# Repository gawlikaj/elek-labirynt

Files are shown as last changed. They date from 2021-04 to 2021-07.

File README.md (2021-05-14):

# elek-labirynt
Handheld Video Game

## Goals
1. Learn how to use EagleCAD (or KiCAD) to develop a PCB design for the project that will connect all hardware that the software is dependent on.
1. Write a bill of materials
1. Apply knowledge and understanding from online coursework and prior in-person coursework into an independent project. (interrupts, finite state machines, usage of GIT, interaction with an LCD display, interaction with analog devices and fundamentals of an RTOS)
1. Learn how the ESP32 microcontroller functions (and how it relates to the chosen board that I will be working with)
1. Develop drivers for SPI-controlled LCD/SD Card, I2C-controlled joystick and LiPo fuel gauge, and GPIO devices connected to the board I am using
1. Consider using and learning how a specific RTOS works such as FreeRTOS
1. Develop a hand-held game via either baremetal firmware programming or code that will run on chosen RTOS (based on #4) utilizing what I did on a text-based high school project

## Notes
The hardware documentation and any media is licensed under the Creative Commons License.  The software and its documentation are licensed under the GNU Public License.

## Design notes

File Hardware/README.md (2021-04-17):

# elek-labirynt Hardware

Hardware Designs and bill of materials for the elek-labirynt project.  I, Andrew Gawlik, have utilized SparkFun parts, their EagleCAD library, 
and their EagleCAD files to create library parts for the schematic and PCB designs as licensed under the Creative Commons Attribution Share-Alike 4.0 License.

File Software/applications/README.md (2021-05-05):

# Applications

This directory contains the test applications and the game engine.  The test applications are designed to test the effectiveness of the drivers implemented.

# Application Layout

The applications are grouped into subdirectories:  Driver_Test and Full_Apps:

* `Driver_Test/UART_Debugger_Test` contains the test application used for the UART debugger driver

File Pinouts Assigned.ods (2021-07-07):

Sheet: Pins
ESP32 Pin # | ESP32 Label | GPIO # | Signal on Thing Plus | Pin on Thing Plus | Signal Type | Signal on Design | Protocol | Function | Device/Driver
25 | IO0 | 0 | 0 | NC | I/O | Unused | NA | Unused | N/A
35 | TXD0 | 1 | RX | NC | I/O | Not Connected on board, but via USB cable | UART |  | Debugger
24 | IO2 | 2 | NA | NC | I/O | Unused | NA | Unused | N/A
34 | RXD0 | 3 | TX | NC | I/O | Not Connected on board, but via USB cable | UART |  | Debugger
26 | IO4 | 4 | A5 | 10@J4 | I/O | BUTTON1 | NA | Button 1 Input | Button 1
29 | IO5 | 5 | SCK | 11@J4 | I/O | SCLK | SPI | Serial Clock | LCD15143
20 | CLK | 6 | NA | NC | I/O | Unused | SPI | Serial Clock | Integrated Flash
21 | SD0 | 7 | NA | NC | I/O | Unused | SPI | Data 0 | Integrated Flash
22 | SD1 | 8 | NA | NC | I/O | Unused | SPI | Data 1 | Integrated Flash
17 | SD2 | 9 | NA | NC | I/O | Unused | SPI | Data 2 | Integrated Flash
18 | SD3 | 10 | NA | NC | I/O | Unused | SPI | Data 3 | Integrated Flash
19 | CMD | 11 | NA | NC | I/O | Unused | SPI | Command | Integrated Flash
14 | IO12 | 12 | 12 | 5@J2 | I/O | BUTTON2 | NA | Button 2 Input | Button 2
16 | IO13 | 13 | 13 | 4@J2 | I/O | BUTTON3 | NA | Button 3 Input | Button 3
13 | IO14 | 14 | 14 | 10@J2 | I/O | LCDCS | SPI | Chip Select for LCD | LCD15143
23 | IO15 | 15 | 15 | 8@J2 | I/O | DC | NA | Data/Command | LCD15143
27 | IO16 | 16 | 16 | 14@J4 | I/O | AWAKE | NA | Awake Switch | Switch
28 | IO17 | 17 | 17 | 15@J4 | I/O | TE | NA | Tearing Effect | LCD15143
30 | IO18 | 18 | COPI | 12@J4 | I/O | CIPO | SPI | Controller Input Peripheral Output | LCD15143
31 | IO19 | 19 | CIPO | 13@J4 | I/O | COPI | SPI | Controller Output Peripheral Input | LCD15143
33 | IO21 | 21 | 21 | 16@J4 | I/O | PWM | NA | Backlight Dimming | LCD15143
36 | IO22 | 22 | SCL | 11@J2 | I/O | Not Connected on board, but via Qwiic Cable | I2C | SCL | Joystick, Fuel Gauge
37 | IO23 | 23 | SDA | 12@J2 | I/O | Not Connected on board, but via Qwiic Cable | I2C | SDA | Joystick, Fuel Gauge
10 | IO25 | 25 | A1 | 6@J4 | I/O | LSPK | DAC | Left Speaker Analog Signal | Left Speaker
11 | IO26 | 26 | A0 | 5@J4 | I/O | RSPK | DAC | Right Speaker Analog Signal | Right Speaker
12 | IO27 | 27 | 27 | 6@J2 | I/O | SDCS | SPI | Chip Select for SD Card | LCD15143
8 | IO32 | 32 | 32 | 9@J2 | I/O | BUTTON0 | NA | Button 0 Input | Button 0
9 | IO33 | 33 | 33 | 7@J2 | I/O | Unused | NA | Unused | N/A
6 | IO34 | 34 | A2 | 7@J4 | Input | Unused | NA | Unused | N/A
7 | IO35 | 35 | NA | NC | Input | Unused | NA | Unused | N/A
4 | SENSOR_VP | 36 | A4 | 9@J4 | Input | BUTTON4 | NA | Button 4 Input | Button 4
5 | SENSOR_VN | 39 | A3 | 8@J4 | Input | Unused | NA | Unused | N/A
3 | EN | NA | CHIP_PU | 1@J4 | Input | Unused | NA | Reset Button | Thing Plus
2 | 3V3 | NA | 3V3 | 2@J4 | Power | 3V3 | NA | Power Supply | All
1 | GND | NA | GND | 4@J4 | Power | DGND | NA | Ground | All
15 | GND | NA | GND | 4@J4 | Power | DGND | NA | Ground | All
38 | GND | NA | GND | 4@J4 | Power | DGND | NA | Ground | All
32 | NC | NA | NA | NC | NA | Unused | NA | Unused | N/A

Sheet: Interrupts
Interrupt | Device | Type
22 | Momentary Pushbuttons | GPIO
none | LCD15143/SPI | I/O
 | Qwiic/Joystick/FuelGauge | Timer
 | DAC1/DAC2 | Timer
 | SleepSwitch | RTCIO

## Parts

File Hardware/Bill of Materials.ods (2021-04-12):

Level | Part Number | Description | QTY | Unit | Unit Cost | Extended Cost | Source | Seller Part Number
0 |  | Complete Hardware Assembly | 1 | Ea |  |  | Self | N/A
1 |  | Momentary Pushbutton Switch - 12mm Square | 1 | Ea | $0.50 | $0.50 | Sparkfun | COM-09190
1 |  | Multicolor Buttons – 4-pack | 1 | Ea | $1.60 | $1.60 | Sparkfun | PRT-14460
1 |  | SparkFun Thing Plus - ESP32 WROOM (U.FL) | 1 | Ea | $20.95 | $20.95 | Sparkfun | WRL-17381
1 |  | SparkFun TFT LCD Breakout - 1.8" (128x160) | 1 | Ea | $29.95 | $29.95 | Sparkfun | LCD-15143
1 |  | SparkFun Qwiic Joystick | 1 | Ea | $10.50 | $10.50 | Sparkfun | COM-15168
1 |  | Mini Speaker - PC Mount 12mm 2.048kHz | 2 | Ea | $1.95 | $3.90 | Sparkfun | COM-07950
1 |  | RES 10K OHM 1/4W 5% AXIAL | 10 | Ea | $0.10 | $1.00 | DigiKey | 10KQBK-ND
1 |  | Lithium Ion Battery – 2Ah | 1 | Ea | $12.95 | $12.95 | Sparkfun | PRT-13855
1 |  | Female Headers | 4 | Ea | $1.50 | $6.00 | Sparkfun | PRT-00115
1 |  | Break Away Headers – Straight | 4 | Ea | $1.50 | $6.00 | Sparkfun | PRT-00116
1 |  | Custom PCB – tentative | 1 | Ea |  |  | Researching | N/A
2 |  | PCB Design and Gerber Files | 1 | Ea |  |  | Self | N/A
3 |  | EagleCAD Free Version | 1 | Ea | $0.00 | $0.00 | Eagle
1 |  | SOLDER LF SN96 21GAUGE .25LBS | 1 | Ea | $33.74 | $33.74 | DigiKey | 473-1102-ND
1 |  | DESOLDER BRAID ROSIN 0.1" 5' | 1 | Ea | $4.33 | $4.33 | DigiKey | 473-1169-ND
1 |  | Lexar Professional LSDMI32GBNL633A 633x Micro SDHC 32GB UHS-I Card with SD Adapter | 1 | Ea | $12.99 | $12.99 | Staples | 24359322
1 |  | LED - Assorted (20 pack) | 1 | Ea | $3.30 | $3.30 | Sparkfun | COM-12062
1 |  | Mini Power Switch – SPDT | 1 | Ea | $1.50 | $1.50 | Sparkfun | COM-00102

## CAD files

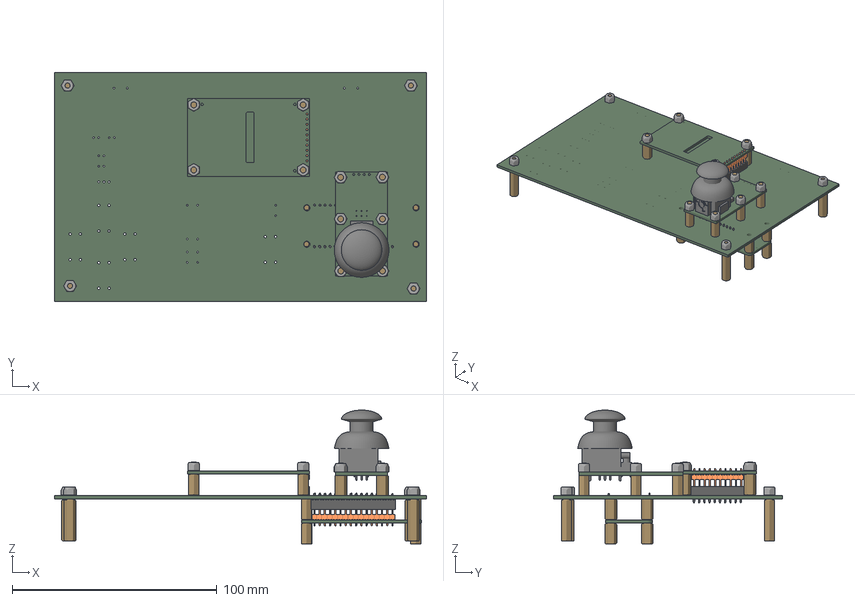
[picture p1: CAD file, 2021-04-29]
Hardware/FreeCad/Assembly with Complete Board.FCStd
181.6 x 111.8 x 65.4 mm
Pin Header - Female - 2.54mm 16pin
Pin Header - Female - 2.54mm 12pin
Pin Header - Female - 2.54mm 10pin
Unified Board
M3_M_TO_F_20MM_STANDOFF C0
M3_M_TO_F_20MM_STANDOFF C1
M3_M_TO_F_20MM_STANDOFF C2
M3_M_TO_F_20MM_STANDOFF C3
hex lock nut m3 C0
hex lock nut m3 C1
hex lock nut m3 C2
hex lock nut m3 C3
Breakout Board COM-15168
M3_M_TO_F_10MM_STANDOFF J0
M3_M_TO_F_10MM_STANDOFF J1
M3_M_TO_F_10MM_STANDOFF J2
M3_M_TO_F_10MM_STANDOFF J3
M3_M_TO_F_10MM_STANDOFF J4
M3_M_TO_F_10MM_STANDOFF J5
hex lock nut m3 J0
hex lock nut m3 J1
hex lock nut m3 J2
hex lock nut m3 J3
hex lock nut m3 J4
hex lock nut m3 J5
Breakout Board WRL-17381
ZL201-40_P2-54_L101_W2-54_H8-011 16pin
ZL201-40_P2-54_L101_W2-54_H8-010 12pin
M3_M_TO_F_10MM_STANDOFF E0
M3_M_TO_F_10MM_STANDOFF E1
M3_M_TO_F_10MM_STANDOFF E2
M3_M_TO_F_10MM_STANDOFF E3
M3_F_TO_F_10MM_STANDOFF E0
M3_F_TO_F_10MM_STANDOFF E1
M3_F_TO_F_10MM_STANDOFF E2
M3_F_TO_F_10MM_STANDOFF E3
Breakout Board LCD-15143
ZL201-40_P2-54_L101_W2-54_H8-9 10pin
M3_M_TO_F_10MM_STANDOFF L0
M3_M_TO_F_10MM_STANDOFF L1
M3_M_TO_F_10MM_STANDOFF L2
M3_M_TO_F_10MM_STANDOFF L3
hex lock nut m3 L0
hex lock nut m3 L1
hex lock nut m3 L2
hex lock nut m3 L3

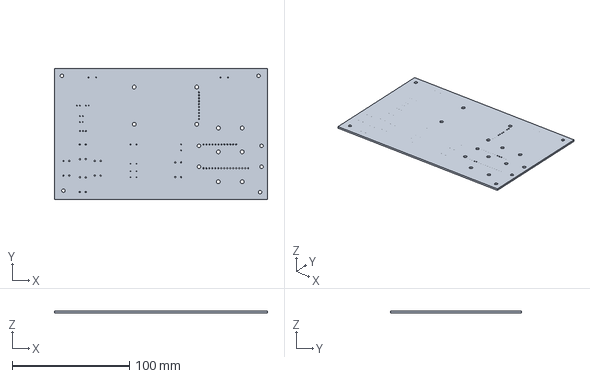
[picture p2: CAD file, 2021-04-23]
Hardware/StepExport/CompleteBoard.step
181.6 x 111.8 x 1.60 mm

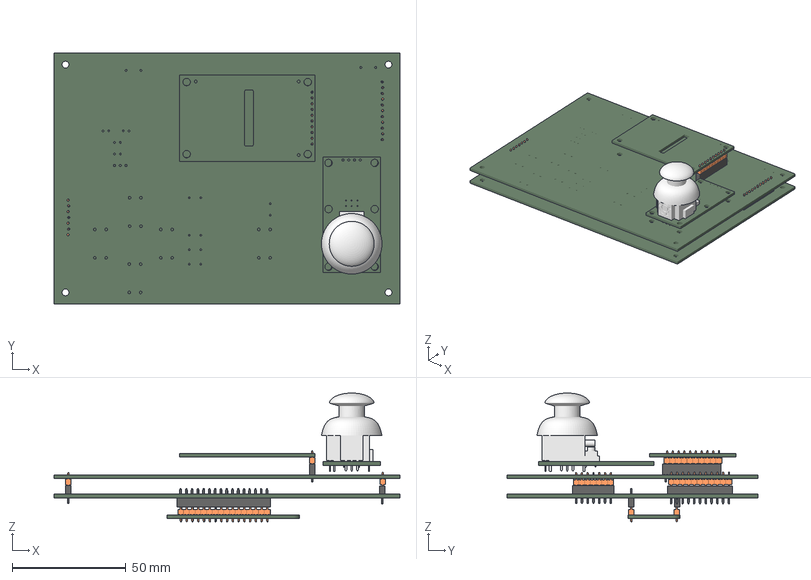
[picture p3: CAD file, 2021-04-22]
Hardware/FreeCad/Assembly with Separate Boards.FCStd
152.4 x 110.5 x 56.8 mm
Pin Header - Female - 2.54mm 10pin
ZL201-40_P2-54_L101_W2-54_H8-9 7pin
ZL201-40_P2-54_L101_W2-54_H8-9 11pin
ZL201-40_P2-54_L101_W2-54_H8-9 10pin
ZL201-40_P2-54_L101_W2-54_H8-011 16pin
ZL201-40_P2-54_L101_W2-54_H8-010 12pin
Pin Header - Female - 2.54mm 12pin
Pin Header - Female - 2.54mm 16pin
Pin Header - Female - 2.54mm 7pin
Pin Header - Female - 2.54mm 11pin

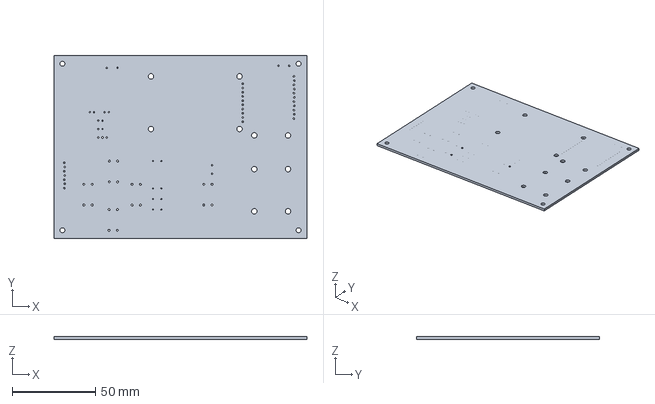
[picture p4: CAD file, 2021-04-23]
Hardware/StepExport/InterfaceBoard.step
152.4 x 110.5 x 1.60 mm

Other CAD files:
Hardware/StepExport/ControllerBoard.step

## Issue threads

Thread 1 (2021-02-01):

Write Bill of Materials

gawlikaj, 2021-02-01:
Write the bill of materials for components used

gawlikaj, 2021-02-01:
Initial Bill of Materials has been create, but part numbers will need to be assigned and more investigation will need to be done regarding pricing of a custom PCB, currently considering vendors that will be reasonably priced for a prototype board.  Considering contingencies if a prototype board is outside of price range.

gawlikaj, 2021-02-09:
Draft of bill of materials has been completed, the rest of the bill of materials is contingent on completion of PCB design and cost of a custom PCB.  Starting new issue after PCB design draft is completed to investigate costs.

Closed 2021-02-09.

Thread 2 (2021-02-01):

Design PCB Layout from Bill of Materials (Interface Board)

gawlikaj, 2021-02-01:
Design the PCB Layout from the Bill of Materials

gawlikaj, 2021-02-01:
Currently 10 buttons and pulldown resistors have been added to the interface board.  Need to convert schematics of SparkFun boards to footprints for my use in the PCB layout

gawlikaj, 2021-02-09:
Still need to convert SparkFun boards to library parts (the schematic part to symbol was simple, but it will take time to precisely define the footprint from the provided board layout).  I have posted a question on the AutoDesk Eagle forum looking for a suggestion to make this conversion less prone to mistakes :  https://forums.autodesk.com/t5/eagle-forum/looking-to-convert-a-pre-manufactured-board-to-library/td-p/10051636

It has gone unanswered for a week and I may consider implementation in KiCad in an effort to continue this.  I already have a KiCad converted top board. Since KiCad does not limit how many layers I can use and it converts Eagle boards/schematics fairly well, I will begin investigating to see how to create a library part in KiCad.

gawlikaj, 2021-02-10:
The SparkFun Eagle files have been imported into KiCad with some warnings related to certain layers being unsupported.  Considering the intent to make them parts that will go on the board being designed, that would be of little consequence.

gawlikaj, 2021-02-11:
Found an interesting approach to creating the library item from the part documented on a forum elsewhere:  https://forum.arduino.cc/index.php?topic=175306.0

gawlikaj, 2021-04-02:
I generated the library versions of the four breakout boards, though I do want to make some tweaks so that I may be able to use them properly in my board design.

gawlikaj, 2021-04-07:
I made the tweaks successfully and started wiring the next part of the board.  My current considerations include splitting this between the controller board and the interface board.

The interface board shall include the buttons, joysticks, speakers, LCD, switch and LEDs
The controller board shall include the microcontroller and the ADC along with the QWIIC cable.  In order to simplify this, I am renaming this issue to reference the interface board and will create a new issue referencing the controller board.

Since this is at the point where I plan to use multiple boards part of this work will also include planning where I will place headers.

gawlikaj, 2021-04-12:
The bill of materials has been updated on issue #8 therefore I will need to make some adjustments accordingly.  Since the Qwiic joystick can be handled through the Qwiic connector, I can leave it off the board design for the interface board, however, I will keep it in mind when I want to stabilize the devices with standoffs and such on the controller board.

gawlikaj, 2021-04-15:
Given the limitation on EagleCAD free edition that limits to 80cm^2, meaning it can be 8cmx10cm, it seems like it will be extremely difficult to produce a board with what I am trying to assemble.  I will instead add all of the components and develop the schematic via EagleCAD then place them and route the traces using KiCad in order to ensure that I can keep the parts and have more freedom to have a larger board, and quite possibly avoid having to design multiple boards.

gawlikaj, 2021-04-15:
For futher clarification on the aspect of multiple boards, KiCad allows for multiple layers, whereas I would need to pay for access to multiple layers on EagleCAD (just like with regards to the board size limitation).

gawlikaj, 2021-04-17:
Updated schematic parts here, as indicated earlier, I will likely find difficulty placing the parts and routing the traces on the board precisely due to board size limitations within the free version of EagleCAD, the schematic and board will be imported into KiCad to complete the process.

gawlikaj, 2021-04-20:
The parts have been fixed, but the board will need to be wired using KiCad in order to ensure enough board space.

gawlikaj, 2021-04-20:
KiCad import has been completed and wiring traces have been completed.  KiCad design rules checker found no problems.

Items to consider:  drill holes for standoffs, board shape, silk screening.

gawlikaj, 2021-04-20:
Also need to update the frame since the autoupdate from EagleCAD is not on KiCad

gawlikaj, 2021-04-20:
Drill holes for standoffs seem like they may need to be handled by adding another "special" part

gawlikaj, 2021-04-21:
Once the drill holes are in place I should be done with this particular board design.  The circuitry and traces have successfully been drawn out using only two PCB layers, which can be helpful in the event that a protoboard is chosen due to costs for ordering a custom PCB.

gawlikaj, 2021-04-21:
Drill holes added for standoffs, for now this is considered complete.

Closed 2021-04-21.

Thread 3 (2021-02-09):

Identification of Available RTOS for ESP32 microcontroller

gawlikaj, 2021-02-09:
Identify available RTOS that can be installed on the ESP32 microcontroller within reason

gawlikaj, 2021-02-09:
https://www.lynx.com/embedded-systems-learning-center/cost-of-a-real-time-operating-system-rtos

gawlikaj, 2021-02-09:
https://www.lynx.com/embedded-systems-learning-center/how-to-choose-a-real-time-operating-system-rtos

gawlikaj, 2021-04-13:
The only RTOS I see API documentation for related to the microcontroller I am using is FreeRTOS.  The C/C++ build system for the official ESP-IDF also uses FreeRTOS in its example files, I will look through to see if there are references to additional RTOS within the IDF.

gawlikaj, 2021-04-14:
After reviewing, the ESP-IDF is built around FreeRTOS, the only other way to get it to work with another RTOS or baremetal for that matter would be to build another framework.  I can look into this another time (it will still be a part of this project), but for now, it seems like FreeRTOS is the best choice for now seeing as it would require more investigation than practical for getting this to work for a project seemingly as simple as this.

Closed 2021-04-14.

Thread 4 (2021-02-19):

Document Hardware

gawlikaj, 2021-02-19:

gawlikaj, 2021-02-19:
Hardware documentation has begun, will also include links/pages regarding how this was implemented.

gawlikaj, 2021-02-19:
Hardware BOM and wiki page for hardware both match with the materials used as of 2021-02-19

gawlikaj, 2021-02-25:
Added documentation regarding a testing plan along with links to some of the datasheets on the wiki

gawlikaj, 2021-04-22:
As indicated on issue #16, the FreeCad assembly drawing will be included on the wiki documentation once it is completed.  Both versions will be included.

gawlikaj, 2021-05-17:
To make this easier, the hardware documentation will be split based on components.  Consequentially this will no longer be an ongoing task, but a tabled one for when the project is ready for assembly.

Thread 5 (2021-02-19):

Order and Receive Parts

gawlikaj, 2021-02-19:
Order and receive parts to begin working on the hardware (this excludes the PCB design as this is to test out a prototype before the PCB is designed)

gawlikaj, 2021-02-19:
SD card has been ordered from Staples, already have the solder, wick, and resistors.  Clarifying ordering information from SparkFun.

gawlikaj, 2021-02-22:
SD card has been received.

gawlikaj, 2021-03-22:
SparkFun order has been sent out, awaiting estimated delivery date

gawlikaj, 2021-03-29:
There is still a backorder on the ADC and the Qwiic cables (used to connect between the ESP32 Thing Plus Wroom and the ADC).

gawlikaj, 2021-04-01:
The Qwiic cables are now in stock, just waiting on the ADC... though I noticed that the breadboards are now out of stock and I am unsure how this will impact my order.  Sending a message to ask about that.

gawlikaj, 2021-04-02:
The breadboards are now showing up as available on the order, still waiting on the ADC.

gawlikaj, 2021-04-12:
The parts have been received today.... after careful inspection, while the ADC was on backorder, I noticed two things:
1) The Qwiic connector and the I2C pins are tied together so I cannot use them as additional GPIO
2) A single Qwiic joystick (I2C interface for the joystick vertical and horizontal interfaces along with the select button) was available

I decided to remove the ADC, both Joysticks and their breakout boards and replace with a single Qwiic joystick.  This will be documented on a revised version of the BOM and wiki.

Closed 2021-04-12.

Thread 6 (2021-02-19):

Add LEDs and Power Switch to Bill of Materials

gawlikaj, 2021-02-19:
LEDs and Power Switch have not been included in the bill of materials.

gawlikaj, 2021-02-19:
Added the LEDs and power switch to the bill of materials

gawlikaj, 2021-02-19:
this should be closed with the last issue update

Closed 2021-02-19.

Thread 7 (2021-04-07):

Design PCB Layout from Bill of Materials (Controller Board)

gawlikaj, 2021-04-07:
Once the interface board is completed, will need to establish a layout that connects the ADC and microcontroller to the headers to properly power up and interact with the interface board.

gawlikaj, 2021-04-17:
This will no longer use the ADC and only includes the microcontroller and headers.

gawlikaj, 2021-04-17:
The reasoning for not using the ADC is that the ADC part, thumb joystick and thumb breakout board parts were all replaced by a single part that has a joystick and performs the ADC and communicates via I2C using the Qwiic cable.

gawlikaj, 2021-04-21:
Use the header pin locations and standoff hole locations from the interface board so that they match up

gawlikaj, 2021-04-21:
The controller board design is complete in regards to existing BOM.

Closed 2021-04-21.

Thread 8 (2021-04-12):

Changes to the Bill of Materials -- Reduction of buttons

gawlikaj, 2021-04-12:
After inspection, the GPIO pins on the ESP32-WROOM Thing Plus suggested for I2C are hardwired to the Qwiic connector on the board.  This means that I need to reduce the number of I/O devices connected directly to the board.  The result, since I really did not need both sets of joysticks nor 10 buttons, was to cut the joysticks and buttons in half.

So now there will be 5 buttons and 1 joystick (this will be a Qwiic joystick as a single part instead of 3 separate parts).
Need to update the bill of materials and the Wiki.

gawlikaj, 2021-04-12:
Both the BOM and the Wiki have been updated reflecting the changes required.

Closed 2021-04-12.

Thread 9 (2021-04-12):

Test SparkFun Thing Plus - ESP32 WROOM (U.FL) -- UART

gawlikaj, 2021-04-12:
Start with some basic firmware for a hello world application that sends a message via UART.  UART seems to be the easiest way to perform debugging and having this piece will help greatly with being able to dump debugging data on regular intervals.  Wireless functionality will be considered on a future milestone after the standalone system is built and tested.

gawlikaj, 2021-04-13:
A useful starting point:
https://docs.espressif.com/projects/esp-idf/en/latest/esp32/get-started/establish-serial-connection.html

gawlikaj, 2021-04-14:
Currently investigating errors in eclipse with the IDF plugin on the project created from the template.

gawlikaj, 2021-04-14:
Using the UART echo project as a template for this part as a starting point

gawlikaj, 2021-04-14:
seems like it works better when I just use the command line interface

gawlikaj, 2021-04-14:
the hello world project executes correctly and I can monitor the data without a problem... now to create the driver and the test program

gawlikaj, 2021-04-14:
I will not include the hello world project in this repository since it was not my code, but I will include my project files (drivers and tests)

gawlikaj, 2021-04-14:
I will be using different parts of the UART example projects to implement this driver and the test program.  I reviewed some of the existing UART example projects.

Will start off with the basics of writing text on a timer to the UART then experiment with abstracting to fulfill the purposes.

gawlikaj, 2021-04-14:
The microcontroller UART has been tested successfully.

Closed 2021-04-14.

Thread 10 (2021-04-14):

UART Debugger Driver Development

gawlikaj, 2021-04-14:
Implement the driver to operate on timed interrupts and read a debugging message sent to it in order to reduce clutter when debugging the system.

gawlikaj, 2021-04-15:
Will be looking at the message buffer to send the data using FreeRTOS

gawlikaj, 2021-04-15:
The debugger will need to be a background task.

gawlikaj, 2021-04-15:
The message buffer is not available with the stable version of the ESP-IDF, currently reviewing the API documentation for the stable version to find a suitable alternative.

gawlikaj, 2021-04-15:
In order to prevent conflicts with the other IO pins on the board, I will need to specify pins for UART0 which is connected to the USB.

gawlikaj, 2021-04-15:
For further information on the UART configuration:
https://docs.espressif.com/projects/esp-idf/en/latest/esp32/api-reference/peripherals/uart.html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

gawlikaj, 2021-04-15:
I may be able to use the UART ring buffer with an ISR to handle debug output.  I can look into it while looking into the pins here:
https://www.espressif.com/sites/default/files/documentation/esp32_technical_reference_manual_en.pdf#uart

gawlikaj, 2021-04-27:
Including this with the breadboard testing project as it will be used for the breadboard testing portion as well...

gawlikaj, 2021-04-27:
As I realized, breadboard testing can be done independent of drivers.  The breadboard testing will use the drivers developed, but will be focused on verifying the functionality of devices by being plugged into the breadboard.  Since UART0 (the UART being used for this driver) can be interacted with via the USB cable, it is unnecessary to include it in breadboard testing, however, the pin assignments uses will be crucial to the design requirements for the rest of the system in order to ensure that there are no conflicts when using the UART Debugger Driver (which will mainly be used for testing).

gawlikaj, 2021-04-30:
Reviewing the API documentation and source code files from the EspressIF ESP32 IDF Programming Guide

gawlikaj, 2021-04-30:
https://i0.wp.com/randomnerdtutorials.com/wp-content/uploads/2018/08/esp32-pinout-chip-ESP-WROOM-32.png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

Has been helpful in identifying the default pins

gawlikaj, 2021-04-30:
Also to help with my project I have included a listing of pinouts for the SparkFun Thing Plus, the pinouts as demonstrated on the schematic for the SparkFun Thing Plus, and what they are wired to

gawlikaj, 2021-05-01:
It works having them set to their default pins (unfortunately the IDF does not seem to indicate which GPIOs these belong to), however after looking at the image for identifying the default pins, I am unsure.... I will need to verify using WaveForms with the logic analyzer to see if there are any signals being sent out to the other GPIO pins before I proceed further.  This would involve soldering the header pins to the SparkFun Thing Plus board.

gawlikaj, 2021-05-03:
After some review of the datasheets and creating a pinout map from microcontroller to thing plus to design, it appears that the default pins for TX and RX will not interfere with any devices... however, after reviewing the datasheet, the default CTS for UART0 appears to be IO19 which connects to the COPI signal and the default RTS for UART0 appears to be IO22 which connects to the SCL used in I2C communication.  However, in order to mitigate confusion I will specify the specific GPIO numbers to match the defaults for TX and RX and unused signals for RTS and CTS.

The current plan is:
RX   - GPIO3
TX   - GPIO1
CTS - GPIO2
RTS - GPIO35

gawlikaj, 2021-05-03:
I had to switch CTS and RTS GPIO numbers due to a kernel panic...

gawlikaj, 2021-05-04:
I am taking the opportunity to utilize the existing build system that the ESP-IDF is using for this project and it's involving some research into both CMake and the ESP-IDF.  The purpose of this is to allow the code to be modularized and so that extra copies of the files will not have to be used, especially with regards to making updates in one location and then potentially forgetting when they need to be used elsewhere...

gawlikaj, 2021-05-05:
The updated structure works as intended, I also switched to ESP-IDF v4.3 for the build system updates, which also includes features that were not available in v4.2... I can take the opportunity to utilize a more appropriate method of setting up the UART Debugger through some of the newer features available in FreeRTOS v10.

gawlikaj, 2021-05-05:
So now I will be investigating the usage of the message buffer

gawlikaj, 2021-05-06:
The UART driver appears to be in working order.

Closed 2021-05-06.

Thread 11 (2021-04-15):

Implement I2C driver for Qwiic Joystick

AJGEmbedded, 2021-04-15:
Read the data from the Qwiic Joystick for the x-axis, y-axis and select button on the joystick.  For the purposes of testing I will be using the UART debugger to output the data read from the Qwiic Joystick.

A strategy I have here is to do two things:
1) allow to read a single parameter from the joystick through individual functions (or one function with an enumeration specifying the value to be read)
2) allow to read all parameters through a single function call

This will be beneficial when I get to the game engine.  Or for that matter, investigating how I may look at building something more sophisticated later down the road.

gawlikaj, 2021-04-27:
Since this also is related to breadboard testing I have added this to the breadboard testing project as well...

gawlikaj, 2021-04-27:
The Joystick driver should not need to be incorporated into breadboard testing directly as the I2C communication for this is connected directly via the Qwiic cable between the ESP32 Thing Plus and the Joystick breakout board, however, when including other I2C devices (such as the Fuel Gauge) which may not have holes for standoffs, it may be necessary to use the pins instead of the Qwiic cable.  In the case of having another device on the I2C bus, it may be prudent to test on the breadboard to ensure that there are no conflicts.

gawlikaj, 2021-05-03:
Reviewing the example code for the I2C project to get an idea... also as identified in the pinout assignments spreadsheet:
SDA - GPIO23
SCL - GPIO22

These pins are essential for working with the Qwiic connect system.

gawlikaj, 2021-05-03:
The hookup guide provided on SparkFun provides the register information for which to retrieve the values of the button and axis:
https://learn.sparkfun.com/tutorials/qwiic-joystick-hookup-guide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

The specific information of importance:
Address - 0x20
0x03      - Horizontal Position MSB
0x04      - Horizontal Position LSB
0x05      - Vertical Position MSB
0x06      - Vertical Position LSB
0x07      - Current Button Position
0x08      - Button Status (Clears after last read)

gawlikaj, 2021-05-06:
starting work on the driver

gawlikaj, 2021-05-06:
I actually have split up the joystick into the qwiic component (for initializing the qwiic system) and the joystick driver itself (for interacting with the qwiic joystick)... this way I can instantiate the qwiic system independently even if I have other qwiic devices.

gawlikaj, 2021-05-07:
a test application has been prepared and the basic functions have been laid out.  Currently in the process of debugging/testing the joystick and qwiic drivers.  There does not seem to be any errors with the joystick portion, for now focusing on the qwiic portion with regards to initialization, transmitting data from the controller to the peripheral (joystick), receiving data from the peripheral (joystick). Any other qwiic I2C component should be easier to implement if connected on the same I2C bus,

gawlikaj, 2021-05-07:
In an effort to test the joystick first, I will try testing with the example code provided in the esp-idf (i2c_tools) to see it it works correctly.

gawlikaj, 2021-05-12:
modeling this after the arduino library functionality provided on SparkFun's website, but I have noticed that I am no longer getting the invalid state error..

the timeout error before was really  a failure for ack (the error message was miss-mapped).  So now the error messages are mapped correctly and the failure for ack was addressed by only using 7-bit addressing and making sure that the address was shifted by 1 and appending the bit for reading/writing as part of the I2C specification.  Now there really is a timeout error and am looking into it (there are also no more invalid state errors).  Also the sections for reading and writing have been broken apart in the qwiic_controller_read_from_peripheral and qwiic_controller_write_to_peripheral.

qwiic_controller_read_from_peripheral has two separate commands (as defined in the I2C driver library from the ESP-IDF)
writing the address of the peripheral and the register to query to the I2C bus
writing the address of the peripheral to the I2C bus and reading the response from the I2C bus

qwiic_controller_write_to_peripheral has a single command (as defined in the I2C driver library from the ESP-IDF)
writing the address of the peripheral, the register to be written to and the data being written

gawlikaj, 2021-05-12:
Currently when reading the data from the joystick I get the following values:
vertical = 16386
horizontal = 16386
select status = 0

the vertical and horizontal values are outside of the range possible from the 10-bit ADC (0-1023)
the select status value reflects not pushing down a button, however, even when the button is pressed it will not change the value

the commands are acknowledged correctly since all command parts have an acknowledge and are not refused.  So the Thing Plus "sees" the joystick.... looking into adding a wait for the response.

Also since each call to qwiic_joystick_chk_status always writes to the select status register after reading from it, I know that writing is working correctly as the command returns with ESP_OK.

gawlikaj, 2021-05-12:
As I thought about it when I was working on the UART driver, since the logger also uses the the same UART port (UART0) the defaults may be conflicting with SCL (the default RTS for UART0)  as documented in issue #10.  This issue will probably come up again with developing the SPI drivers for the LCD and SDCard with the CTS.  It would be best to work on adjusting the logger to use GPIO2 for CTS and GPIO35 for RTS to address and prevent these possible conflicts.

gawlikaj, 2021-05-12:
Currently checking out the data from Waveforms by looking at the Logic Analyzer Traces

gawlikaj, 2021-05-12:
The data from Waveforms indicates that there is something peculiar.  I recognize the start, stop and nack conditions, however I am seeing errors detected on the logic analyzer for the data streamed...

I also noted that there seems to be a way to disable hardware control of the UART (assuming it is not already disabled) which could eliminate such a possible conflict.

gawlikaj, 2021-05-13:
The data from Waveforms indicates that there is something peculiar.  I recognize the start, stop and nack conditions, however I am seeing errors detected on the logic analyzer for the data streamed...

I also noted that there seems to be a way to disable hardware control of the UART (assuming it is not already disabled) which could eliminate such a possible conflict.

For now I will table the Qwiic drivers until after I get to the same point with the SPI drivers.

AJGEmbedded, 2021-08-17:
There seems to be some issues implementing this with the ESP-IDF for now, so a functional test of the existing SparkFun arduino library has been implemented in the way that I intend to use this.  Implementing the project in C/C++ will be revisited later once the rest of the project has been implemented  See #39

AJGEmbedded, 2022-04-01:
After reviewing the arduino libraries, I uncovered that it is necessary to set a timeout value for the I2C bus as of now, the interactive test is working and the component is configurable for instruction timeouts and specific bus speeds.

Closed 2022-04-01.

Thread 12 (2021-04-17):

Design a complete board for cost comparison

gawlikaj, 2021-04-17:
After discussing with an employee at a PCB manufacturer, it was suggested that a multilayer board may be more cost effective than two double-layer boards.  Try to implement a PCB with all components

gawlikaj, 2021-04-17:
Both an Eagle version and a KiCad version have been prepared, I still need to route the traces for the board and place the parts.

gawlikaj, 2021-04-19:
Some parts have been placed, but I may need to edit the buttons so that I can access all four terminals since the library part only wires two pins where some of the other pins (and only allows connection via the top) may allow more efficient wiring to reduce the layers being used.  Some other thoughts:  since the Joystick is not being connected through circuit board traces, but instead by the Qwiic cable, I may want to revise that so the pads and pins are removed from it (only leaving the drill holes for standoffs).

gawlikaj, 2021-04-22:
Since the controller and interface boards have been designed each with a two layer PCB, it seems likely that the PCB design for the complete board will require four layers.

gawlikaj, 2021-04-22:
The "complete" version of the board has been designed.

Closed 2021-04-22.

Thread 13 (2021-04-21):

Add LiPo "Fuel Gauge" to BOM and hardware

gawlikaj, 2021-04-21:
Add a LiPo fuel gauge to detect the charge level of the rechargeable battery used to power this device.

One that is available that uses the Qwiic connect system (and thus no additional individual wires/traces):
https://www.sparkfun.com/products/10617

gawlikaj, 2021-04-21:
This will be added to the complete board and the controller board after they are designed without it

gawlikaj, 2021-04-22:
Since both the controller and "complete" boards have been designed, I need to do some investigation regarding the LiPo fuel gauge pin layouts and usage.

gawlikaj, 2021-04-22:
Also need to verify that the FreeCad assembly drawings are accurate in terms of pin headers and holes for the boards as per issue #16  so that it is confirmed that the board is designed correctly.  If they need to be redesigned, it could make the design issues more complicated to deal with.

gawlikaj, 2021-04-26:
Since the pin headers and holes for the boards are updated, I am now investigating the LiPo Fuel Gauge.  The datasheet is listed here:  http://cdn.sparkfun.com/datasheets/Prototyping/MAX17043-MAX17044.pdf

In addition to the datasheet, I will also be reviewing the schematics for both the ESP32 Thing Plus U.FL and the LiPo fuel gauge which I have already downloaded in Eagle Format.

gawlikaj, 2021-04-26:
From the schematics, it appears that Vbatt on the ESP32 Thing Plus U.FL would connect to the + signal on the fuel gauge grounding all as appropriate.  The SDA and SCL pins are self explanatory though I may still attempt to use the Qwiic Cable instead since a Qwiic port is provided (which would reduce the number of traces used, however, since I want to ensure that this is going to remain stable, I will most likely use all pins (since there are no drill holes).  This will mount on the bottom side of the board (as indicated on the wiki, bottom mounted peripherals will be on the controller board in the split/2-board version).

gawlikaj, 2021-04-26:
Based off of the reading from the schematics and datasheet the following pin connections should be used:
SDA -> 23
SCL -> 22
QST -> GND (not using hardware Quick Start, will write to the register instead if necessary)
ALT ->  pick one of the unused GPIO pins on the microcontroller:  A2,A3, A5  to incorporate alert interrupt feature, otherwise, do not connect
+    -> Vbatt
-    -> GND

Notes:  my previous schematics suggest to not connect to pins 22 and 23 on the microcontroller as they are also connected to the Qwiic port on the ESP32 Thing Plus, however, since the Qwiic port uses I2C just like the LiPo Fuel Gauge, this should not be a problem, however it will be necessary to test/verify.

AJGEmbedded, 2022-04-02:
So I am working with two different fuel gauges now:  the Qwiic Fuel Gauge - MAX17048 and the SparkFun LiPo Fuel Gauge

The MAX17048 uses the qwiic cable, the jst battery connector, and seemingly would connect to the SparkFun Thing Plus through the battery

The first one actually requires pins and soldering but no holes for standoffs, so ideally I would like to get this working with the second fuel gauge.  Since the driver seems to be working with the second fuel gauge, I will continue down that path for now.  Will need to obtain the appropriate wire, test and crimp.

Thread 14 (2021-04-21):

Add Standoffs to BOM

gawlikaj, 2021-04-21:
Standoffs go hand-in-hand with the drill holes, add the standoffs to the BOM and order them
https://www.sparkfun.com/products/10463
https://www.sparkfun.com/products/10739

gawlikaj, 2021-04-22:
the number of standoffs and screws will depend on the PCB design version used:  split vs complete, however the BOM can include the largest number required and it can be reduced later.

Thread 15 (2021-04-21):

Update Breakout Board Footprints

gawlikaj, 2021-04-21:
The breakout board footprints after exporting to gerber and reimporting to Eagle have demonstrated that there portions that should not be present some items need to be present.  Since it would need to be rewired if edited in Eagle and imported to KiCad, it would be easier to switch the layers in KiCad and go through the Gerber export process (plot) and then reimport to Eagle.

This is in relation to the following issues:  #2 #7 #12

Since #2 has already been marked as completed, this is a new issue that needs to be addressed.

gawlikaj, 2021-04-21:
Footprints are updated in both the interface board and controller board, they still need to be updated on the complete board.

gawlikaj, 2021-04-22:
All library footprints are updated and used appropriately.

Closed 2021-04-22.

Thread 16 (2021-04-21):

Create a FreeCad Assembly Drawing

gawlikaj, 2021-04-21:
Create a FreeCad assembly drawing to illustrate how the breakout boards and two variations (split Controller/Interface vs Complete) are assembled with the standoffs and header pins

gawlikaj, 2021-04-21:
Also need to upload the assembly to the wiki as well

gawlikaj, 2021-04-22:
The split Controller/Interface board version has been started with both boards exported from KiCad to "step" format for use in FreeCad and the "step" files have been imported accordingly.   Need to export the existing design files for the breakout boards and include headers and standoffs for the rest of the split board version.  The breakout board "step" files will be useful for the complete board version as well.

gawlikaj, 2021-04-22:
The PCB board designs are all imported.  As mentioned earlier, the breakout boards, header pins and standoffs need to be added.

gawlikaj, 2021-04-22:
Found some header step files which I can use for my assembly drawings off of GrabCad.com

The source links for the header pins here:
https://grabcad.com/library/pin-header-female-double-2-54mm-different-pin-numbers-1
https://grabcad.com/library/pin-header-male-2-54mm-different-pin-numbers-1

gawlikaj, 2021-04-22:
Found some standoff step files which I can use for my assembly drawings off of GrabCad.com

The source link for the standoffs here:
https://grabcad.com/library/hexagonal-spacers-m3-m-f-hex-5-1

gawlikaj, 2021-04-22:
Noted there are some missing drill holes for the Qwiic Joystick, this should not be a problem for the Interface Board, but it may be problematic for the "Complete" board...  Creating a separate issue for this.

gawlikaj, 2021-04-22:
So the remaining items to work on for this issue are:
correct size standoffs
update interface board
update "complete" board

gawlikaj, 2021-04-23:
The previous standoff library listed is too long for the parts I found on sparkfun

found two others of configurable length:
https://grabcad.com/library/hexagonal-spacer-m3-mf-configurable-length-entretoise-hexagonale-m3-mf-1
https://grabcad.com/library/hexagonal-spacer-m3-ff-configurable-length-entretoise-hexagonale-m3-ff-1

gawlikaj, 2021-04-29:
The "complete" board has been updated to include the standoffs and nuts as listed in the acknowledgements.  Some additional thoughts:  it would probably be a good idea to also include the resistors, switches and LEDs that are soldered onto the board (and if possible the components that are on the breakout boards as only the boards themselves were exported to step format).  These drawings also allow the possiblity of designing a case (which would be a separate issue if pursued).

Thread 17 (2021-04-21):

Remove excess drill holes from KiCad design

gawlikaj, 2021-04-21:
The extra drill holes for mounting the breakout boards in the interface board schematic appear to be unnecessary as they are already included in the footprints of the parts laid out on the board.  Remove them to mitigate confusion.

gawlikaj, 2021-04-21:
Since the holes were only in the interface board and the interface board has been updated, this is considered complete.

Closed 2021-04-21.

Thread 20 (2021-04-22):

Fix Qwiic Joystick Footprint to include two missing drill holes

gawlikaj, 2021-04-22:
The Qwiic Joystick part is mising the two middle drillholes on the KiCad footprints.  That can be problematic if the drill holes and standoffs are not present, which may result in the board snapping if too much pressure is applied.

gawlikaj, 2021-04-23:
The drill holes for the Joystick breakout board have been added and any necessary changes have been made to accommodate it based on the Design Rules Checker in KiCad.

Closed 2021-04-23.

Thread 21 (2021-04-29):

Review parts on designed boards (LED and Resistor)

gawlikaj, 2021-04-29:
Review parts on designed boards and update as appropriate, which may impact the traces already placed on the PCB design.

Considerations:
Resistor pitch, finding appropriate resistor drawings on grabcad.com (after exporting design to step format)
verify LEDs selected match the size/pitch of the corresponding items on the PCB design (and find corresponding cad files from GrabCad)

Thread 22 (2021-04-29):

Prototype Sleep Switch Circuit

gawlikaj, 2021-04-29:
Prototype the sleep switch circuit as designed in the schematic on a breadboard.  Test the output as well.

AJGEmbedded, 2021-08-15:
A prototyped sleep switch circuit has been implemented on breadboard, it works when powered by the Analog Discovery 2 with a 3.3V V+ supply.  The issue is when powering the same circuit via the microcontroller.  LEDs were used for indicators with the switch and unfortunately produced current way too small to not drive the LEDs.  In this scenario, it might be easiest to build separate control and indicator circuits.  The control circuit being tested right now does not have a capacitor, however, this could be implemented like the momentary pushbutton debounce circuit without the diode and pull-up resistor, since the switch is a DPST as opposed to an SPST momentary pushbutton.  With the DPST, there are two signals being used as "inputs" ground and power.  With the possibility of bounce, an RC filter with the schmitt trigger can be used to debounce this circuit.  The resistor is to be connected between the middle pin of the DPST switch and the input of the schmitt trigger.  The capacitor is to be connected between the input of the schmitt trigger and ground.

The inticator of the sleep switch circuit is composed of only 2 LEDs and 2 resistors:  a resistor connected between +3.3V and the anode of one LED.  That LED's cathode is then connected to the GPIO pin used for the indicator.  The same GPIO pin used for the indicator is also to be connected to another resistor.  The other end of that resistor is to be connected to the anode of the second LED.  The cathode of the second LED is to be connected directly to ground.

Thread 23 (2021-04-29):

Prepare hardware assembly document  -ongoing

gawlikaj, 2021-04-29:
Prepare an assembly document and upload to the wiki.  This includes things like the assembly drawing, soldering pin headers to breakout boards and anything else that does not directly require software coding.   This will be ongoing until the PCB is finalized and any other hardware choices made are also finalized.

gawlikaj, 2021-04-30:
Hardware assembly instructions have been prepared for the Joystick, Microcontroller and LCD/SD pre-manufactured boards for the purposes of attaching headers/cables and allowing breadboard connectivity.

gawlikaj, 2021-05-17:
Hardware assembly documentation will be split between the different modules so this is no longer and ongoing task and is not required.

Closed 2021-05-17.

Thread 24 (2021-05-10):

UART Debugger Printing too fast

gawlikaj, 2021-05-10:
The UART Debugger is outputing too fast and even overwhelming the display...

gawlikaj, 2021-05-10:
The problem was due to the buffer being output even when there was no new data present, it instead was repeating the same message.  I found on the xReceiveMessageBuffer API  documentation from FreeRTOS that it returns the number of bytes in the message received.  The solution was to check to see if the bytes received was greater than 0.

gawlikaj, 2021-05-10:
I also made modifications to the driver test to instead display a loop counter rather than simply Hello World endlessly

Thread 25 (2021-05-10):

UART Debugger displaying strange characters with newlines

gawlikaj, 2021-05-10:
On strings with newlines and carriage returns the UART Debugger is cutting off the first two characters in the output of the first message and afterwards displaying strange characters... test to see if the newlines/carriage returns are necessary to provide the desired effects and if not, identify a way to correct the issue to present the desired effects...

gawlikaj, 2021-05-10:
the '\r' and '\n' characters are in the correct locations, so there must be another issue...  by this same token, it does provide some insight into adding some additional functions that may be beneficial which I will add as a feature request.

gawlikaj, 2021-05-10:
The symbols with the new lines issue has been addressed, the uart_write_bytes function needed to be provided with the number of bytes received from the xMessageBufferReceive otherwise it included data that was not relevant.  The issue pertaining to the missing two characters of the very first debugger message seems to be another issue to be investigated.

gawlikaj, 2021-05-10:
This issue is now resolved

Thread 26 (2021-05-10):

Implement helper library for inserting numbers into strings

gawlikaj, 2021-05-10:
Since the driver development has included several versions of implementing number to ASCII conversion, it seems like a logical step would be to include string helper functions in order to remove the repeated code.  Currently the ASCII conversion is being used with the UART debugger, but it may be possible to use this for writing to the LCD once that driver is developed.

gawlikaj, 2021-05-11:
this has been successfully tested in the UART Debugger with the loop counter in lieu of the "hello world" that was repeatedly being displayed.  The loop increments correctly and is displayed as expected.

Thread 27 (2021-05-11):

Implement Qwiic I2C Driver for LiPo Fuel Gauge

AJGEmbedded, 2021-05-11:
Implement a driver for the LiPo Fuel Gauge.  Need to be able to detect the statement of charge.  Can test this with both the sparkx and the spark fun supported boards to see which one works the best as well...

Since the Qwiic Joystick driver shares a core component with this (namely the Qwiic Controller) this should be easily implemented upon successful implementation of the Qwiic Controller.

AJGEmbedded, 2022-04-01:
Since the qwiic joystick is working, the fuel gauge drivers should also be working considering that the commands were looked up earlier when this was prepared.

AJGEmbedded, 2022-04-02:
In this seems to be ready, creating additional issue for more exhaustive testing

Closed 2022-04-02.

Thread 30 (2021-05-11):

Implement DAC Speaker Drivers

gawlikaj, 2021-05-11:
Implement and test analog speaker drivers that utilize the digital to analog converter built into the microcontroller.

This may require additional circuit design, possibly including amplification circuitry.

gawlikaj, 2021-05-14:
Updated projects listing so that it can be separated by component rather than task.  Seeing as tasks related to breadboard testing, drivers and hardware design are inter-connected, it seems to make more sense to break it down this way.

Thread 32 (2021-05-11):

Remove UART Debugger from FreeRTOS version

gawlikaj, 2021-05-11:
The built-in esp_log header from the ESP-IDF performs everything that the UART Debugger was intended to perform and more.  The UART Debugger itself will be fine for use in the baremetal version...

That being said, the UART Driver and test application will need to be redesigned for that... so implementation will be tabled while working on the FreeRTOS implementation.

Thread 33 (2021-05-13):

Speaker Circuitry

gawlikaj, 2021-05-13:
Look into adding amplification circuitry between the DAC output and the speakers.

A starting point is here:
https://www.ti.com/lit/an/slyt342/slyt342.pdf

gawlikaj, 2021-05-14:
This should be doable with one op-amp per speaker and one potentiometer per op-amp.  Though this will also require adding some resistors in a voltage divider to get a middle voltage to use for reference.  It would not be a true ground, but it should allow the op-amps to amplify the sound if necessary.

AJGEmbedded, 2021-09-03:
Tested out filter stages separately to filter out DC and high frequencies contributing to quantization error.  Calculating the appropriate resistor values in order to achieve the maximum amplitude allowed by the speakers given that their specifications allow for 0.5W each and the speakers have an impedance of 8 ohms each.  This results in a maximum amplitude of 2V from reference ground.  The maximum gain allowed is thus 1.21 (or 1.6dB)

AJGEmbedded, 2021-09-14:
The speakers still need to be connected to verify that sound will be produced, however the base circuitry has been designed, implemented on a breadboard and tested with the Digilent Analog Discovery 2 oscilloscope feature and waveform captures have been saved.

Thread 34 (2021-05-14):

Add ability to adjust Backlight Brightness of LCD

gawlikaj, 2021-05-14:
Since the backlight of the LCD uses an LED and uses a PWM signal, look into using a potentiometer for adjusting the backlight brightness.  This should be doable with the built-in ADC on the microcontroller.

gawlikaj, 2021-05-18:
the backlight can be configured using the LedC driver built-in the ESP-IDF, since it is a PWM designed for LEDs, this should work with the LED backlights

gawlikaj, 2021-05-24:
I ordered a knob and rotary encoder that I can use for controlling the brightness.  It arrived today, so I can use the rotary encoder to adjust the backlight brightness once I write a driver that would accommodate that.

So the ability to adjust the backlight brightness of the LCD is split into two sections:
1) driver to read position of the encoder
2) use the LEDC driver builtin the ESP-IDF to control the brightness of the LCD using PWM and adjusting the duty cycle.

Some caveats... the encoder will use two GPIO pins and the encoder software only captures relative position, however, I could put something in the software that remembers the last state of the encoder when it was powered on, or I could prompt the user to set the knob to a certain position.

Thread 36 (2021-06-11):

Write Drivers for Momentary Pushbuttons (Buttons 0-4)

gawlikaj, 2021-06-11:
Write the Interface Drivers for the momentary pushbuttons using the GPIO.
This corresponds to buttons 0-4 (red, yellow, green, blue, black respectively)

gawlikaj, 2021-06-11:
Button 0 (Red) corresponds to GPIO32
Button 1 (Yellow) corresponds to GPIO33
Button 2 (Green) corresponds to GPIO12
Button 3 (Blue) corresponds to GPIO13
Button 4 (Black) corresponds to A4 (GPIO36)

gawlikaj, 2021-06-14:
Wired up the circuit and before starting to write the drivers, I decided to check the pins using the logic analyzer from Waveforms... noted that the Red and Yellow buttons appeared to have some random fluctuations and the green button was behaving normally... the blue and black buttons were not responding appropriately.  Taking time to verify the wiring.

When I get to writing the drivers, originally I was planning to use the built-in GPIO settings, however, it seemed like it might be good to use the registers for the purposes of practicing.

This means setting the IO registers for the corresponding GPIO so that they are configured as inputs.  Since I am using 10k ohm resistors, I should not need to use internal pullup resistors.

The random behavior observed for the red and yellow buttons may be due to pre-existing configurations on the ESP32, so for now I will test without having the GPIO connected.

gawlikaj, 2021-06-14:
Reseating the momentary pushbuttons in the breadboard as they did seem a bit loose..  now they are secure in the breadboard and don't jump when pressing/releasing

gawlikaj, 2021-06-14:
Also noted that one half of the breadboard may not transmit the power/ground lines all the way across on it's side ...columns numbered < 30 appear to not be connected to columns numbered > 30 on either side of the breadboard.... so I am keeping the buttons all on the same half of the breadboard and wiring the power supply lines on that side of the breadboard... the microcontroller is remaining on the other half of the breadboard.  Once this has been verified by the Logic Analyzer a picture will be uploaded to the wiki page reflecting the wiring.

gawlikaj, 2021-06-14:
the signals are displaying correctly now

gawlikaj, 2021-06-15:
started the work on the configuration registers and reviewed the technical reference manual regarding their usage for configuring the GPIO buttons and corresponding IO_MATRIX signals

gawlikaj, 2021-06-16:
With a test not using interrupts, button0, button2, and button3 behaved correctly.

I also noticed that when pressing button3 that it also activates an LED on the microcontroller board... would need to investigate what is causing the LED to light up when this should be an output only.

Also button1 and button4 are not responding, which indicates that more investigation is required for them.

gawlikaj, 2021-06-16:
This test was performed while the logic analyzer has been connected to the buttons to confirm correct voltages.

gawlikaj, 2021-06-16:
Upon further inspection when reading the data from the input registers it included extraneous bits.  I have masked those bits out.

Currently only button1 is having a problem with being read correctly.

gawlikaj, 2021-06-16:
After outputting the GPIO_IN_REG and GPIO_IN1_REG, there appears to be no change with regards to pressing the yellow button (Button1).  Next thought is to check to see if there is a problem with the pin for GPIO33

gawlikaj, 2021-06-17:
Using the continuity tester between the button signal terminal and the header pin showed it was connected -- verified wiring
Using the continuity tester between the button signal terminal and the GPIO pin on the ESP32 verified that the signal is connected to where it should be and that there is no connection problem between the ESP32 and the GPIO header pin

On the Technical Reference Manual on page 47 it states that the GPIO Matrix does not need to be configured to read any GPIO pin, but the IO_MUX must be configured to set the FUN_IE bit.  This has already been implemented in the driver.  I may check the forums for information on what is causing GPIO33 to not read the button1 signal.

gawlikaj, 2021-06-17:
Alternatively, I can create a minimal UART driver and remove the existing log reference in the event that the built-in log is causing a problem

gawlikaj, 2021-06-17:
As for the on-board LED, after reviewing the EagleCAD Schematic for the SparkFun Thing Plus ESP32 U.FL, I realized that it is directly connected to GPIO13, so I am not worrying about that at present, especially since GPIO13 is not having an issue.

gawlikaj, 2021-06-17:
From reviewing a discussion on the topic about GPIO33 having difficulty, there is a potential issue related to the XTAL32K register... after reviewing where the RTC IO pins are assigned, they map GPIO33 and GPIO32 to 32K_XN and 32K_XP

gawlikaj, 2021-06-17:
So the 32K_XN and 32K_XP pads need to be routed to the IO_MUX and it has been confirmed by testing to see what happens if the RTCIO_XTAL_32K_PAD_REG bits 17 and 18 were explicitly set as opposed to cleared and button0 failed to respond.  I have reverted to clear.

gawlikaj, 2021-06-17:
While testing things out, the internal pull-down resistors work quite well with the setup

gawlikaj, 2021-06-17:
When using the internal pull-down resistors instead of the external resistors with the setup and reviewing the logic analyzer traces I observed the following:

the Red (button0)   has a lot of noise on it and creates interference with button1, but it displays the correct result on the test application
the Yellow (button1) is generating the correct signal, but has interference with button0 and the test application does not show the output
the Green (button2) is generating the correct signal and the correct result is shown on the test application, but has interference with button1
the Blue (button3) is generating the correct signal and the correct result is shown on the test application, but has interference with button1
the Black (button4) is generating the correct signal and the correct result is shown on the test application

It appears that external pull-downs are better for this case due to signal integrity.  Also taking note that the mystery about GPIO33 is still being investigated.

AJGEmbedded, 2021-06-18:
While trying to figure out the issue with GPIO33, I sent in some questions about it...  in the mean time I started testing with interrupts on the API for a base test... they seem to be working fine (again except GPIO33).  Though I did notice when counting button presses that each press was not a single hit.  Since this appears to be a problem requiring debouncing code I found a resource on debouncing buttons with interrupts on the ESP32 on this link:
https://www.switchdoc.com/2018/04/esp32-tutorial-debouncing-a-button-press-using-interrupts/

AJGEmbedded, 2021-07-01:
I loaded up the latest code on the repository, including testing applications (both standalone and using unity).  There is still a problem with GPIO33 not acting as expected.

AJGEmbedded, 2021-07-01:
A software implementation of switch debouncing has been added so that it does not need to be addressed within a user-defined handler assigned to a button.  This is configurable using idf.py menuconfig  Debounce time is measured in milliseconds.  This has been tested successfully with 200ms as the debounce time.  100ms still allowed 2 triggers when there should have been only one trigger, so it might be possible to try checking between 100ms and 200ms to find the smallest debounce time that will work in order to allow for optimal responsiveness.

AJGEmbedded, 2021-07-01:
The alternative to this software implementation would be to either use an RC filter in order to mitigate the signal bouncing or to use flipflops  both of these strategies are hardware solutions to the same problem.

An RC filter implementation would require calibration of the time constant (R*C) to ensure that the voltage level is at least at the minimum threshold value for a logic level 1 when pressed.  Since the SparkFun Thing Plus ESP32 has 3.3V for it's power supply and for logic level 1, since the threshold value is 0.75*VDD this should come out to 2.475V.  Some circuit analysis will need to be performed in order to ensure that the circuit used will filter as expected.  Since this is still under development, it might be worth exploring and explaining in the wiki.

AJGEmbedded, 2021-07-07:
The alternative implementations for debouncing will be considered later, however to address the issue with the yellow button, I have switched the GPIO pin used for button1 from GPIO33 to GPIO4 (another that was unused.

AJGEmbedded, 2021-07-07:
The driver successfully reads button presses and responds to interrupts, however, a new issue has arose. When pressing a button for a longer period of time the button registers two presses.  Considering a different implementation of debouncing.

AJGEmbedded, 2021-07-07:
Also discovered that pressing buttons rapidly in succession does not register all button presses, this is probably due to the debounce time set being too high.

AJGEmbedded, 2021-07-07:
Since I know that the logic analyzer is recording the signal that I would expect, it seems like I may need to the use the oscilloscope with some of the buttons to identify a more appropriate debounce time.

AJGEmbedded, 2021-08-04:
Drivers have been altered so that debouncing is not in the software.  The software debouncing has been replaced by hardware debounce circuitry.

AJGEmbedded, 2021-08-04:
Further clarification that the circuit used here is using debouncing circuitry with a pull-up resistor and an inverting schmitt trigger instead of a pull-down resistor.  The pull-up resistor and inverting schmitt trigger essentially create the same sort of behavior.  But that discussion is in the #37 presentation and #38 designs.

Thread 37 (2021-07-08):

Prepare Presentation for Momentary Push Buttons

AJGEmbedded, 2021-07-08:
Start with a LibreOffice Impress Presentation to come up with an overview of push buttons, how to use them in a circuit, problems encountered, examples of  what they are used for, interrupts, how to address problems, testing and learning experiences, and any reference links.

AJGEmbedded, 2021-07-22:
Started some research into proper debouncing of buttons and prepared calculations and a starting presentation for the momentary push buttons.

AJGEmbedded, 2021-07-22:
In particular the focus has been to include the hardware and calculations of resistor ranges

AJGEmbedded, 2021-07-22:
The calculations have been prepared in Maxima and the Formulas used in the presentation are in LibreOffice Math.  The presentation itself is in LibreOffice Impress.

AJGEmbedded, 2021-07-23:
The next step is to perform the analysis calculations for a RC filter with a diode and then the Schmitt trigger

AJGEmbedded, 2021-07-29:
The diode portion of the calculations has been completed and a design is prepared.  The current phase is working on the Schmitt Trigger variation which will effectively make the signal fit for a digital signal.

AJGEmbedded, 2021-08-03:
The Schmitt Trigger variation was completed and formulas have been inserted into the presentation (except for the Schmitt Trigger portion which will be added shortly).  Still need to add in some pictures and waveform captures before the presentation is ready.

AJGEmbedded, 2021-08-03:
The formula updates for the presentation have been uploaded... still need to add in the pictures and waveform captures for the presentation to be complete

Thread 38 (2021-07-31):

Momentary Pushbutton Debounce Circuitry

AJGEmbedded, 2021-07-31:
After doing some research on a hardware solution to debouncing.  I noticed that I need to include some additional parts to ensure a clean signal for the switches.

I have performed the calculations as I was going through the presentation, however, I need to also update the Bill of Materials.  To make things easier to track, I will separate the bill of materials into an overview and broken down by module.  When it comes to shared modules there will be a note (referencing the first module that uses the specific part) without a part number or ordering information.

I have also completed a test via the Digilent Analog Discovery 2 with Waveforms application that appeared to be successful and took measurements from the logic analyzer for rise and fall times which appeared to be within reason

AJGEmbedded, 2021-08-03:
Obtained the step model as well as the footprint and symbol files for both the diode and the Schmitt Trigger.  Thinking it might be best to use pin headers as much as possible for both the buttons and schmitt trigger moving forward to allow ease of part replacement.  As for the resistors, capacitors and diodes, that might be better either directly on board or using surface mount equivalents.  For now planning on using the through hole parts I have been using for breadboard testing.  Perhaps a surface mount equivalent will be explored later.

AJGEmbedded, 2021-08-03:
Obtained step model and footprint and symbol files for similar resistors

AJGEmbedded, 2021-08-03:
the bill of materials was updated to include the parts on the modules tab.  Final bill of materials will be updated when all modules currently planned are completed.

AJGEmbedded, 2021-08-03:
I did purchase a resistor and capacitor kit from SparkFun which I am currently using for the breadboard testing.

AJGEmbedded, 2021-08-03:
Surface mount components appear to have a minimum quantity beyond the intended budget for this project.  Will stick with the throughhole components

AJGEmbedded, 2021-08-03:
Need to get footprint references for the resistors, capacitors and switches

AJGEmbedded, 2021-08-03:
The schematic portion has been wired up for the debounce circuitry via KiCad

AJGEmbedded, 2021-08-04:
There are still occasions where button presses are either missed or counted twice, but most of the time they are counted once.

AJGEmbedded, 2021-08-04:
When testing and having the power and ground pins from the SparkFun Thing Plus ESP32 U.FL to the ground and power supply rails on the breadboard that contains the buttons and debounce circuitry I did notice that I needed to reinforce the ground with a ground from the Analog Discovery 2.  I am a bit concerned regarding this and thus looking into issues regarding ground noise.  I will take a look at the power supply lines using the oscilloscope functionality of the Analog Discovery 2 both with the ground connected and without.  I should be seeing a steady 3.3V between power and ground.

AJGEmbedded, 2021-08-04:
When I probe the ground supply with the oscilloscope it seems steady, but it's not quite 3.3V, it's dropped to 3.18V and there seems to be some electrical noise associated with it.

AJGEmbedded, 2021-08-04:
I may need to add a bypass capacitor to eliminate the noise.

AJGEmbedded, 2021-08-15:
So after some inspection connecting two oscilloscope probes to the circuit, one to ground and one to vcc, tying the ground clips together, I observed that noise is present when the wires are disturbed.  I suppose this makes sense when using a PCB this will likely not be a problem.  I could test this by using shorter jumper wires rather than the lengthy jumper wires I am using.  For this scenario, I might want pick different pins for the buttons.  When I reviewed the design for the PCB, it seemed like it would be advantageous to switch some GPIO pins around.  I would probably want to verify that the desired pins would permit all planned functionality of the system.

AJGEmbedded, 2021-08-15:
Also upon further inspection, it appears that the inverting schmitt trigger may not be getting enough power after a button is pressed

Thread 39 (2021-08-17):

Implement Arduino Test of Qwiik Joystick

AJGEmbedded, 2021-08-17:
Implement the Arduino Test of the Qwiic Joystick for faster prototyping and confirmation of circuitry.

AJGEmbedded, 2021-08-17:
The arduino test sketch for the Qwiic Joystick has been compiled and tested.

AJGEmbedded, 2021-08-17:
Minor error detected when running through the code.  The getButton function only gets the current state and not since the last time it was checked.  Switched to checkButton and the issue has been resolved.

AJGEmbedded, 2021-08-17:
Completed testing successfully with no further errors

Closed 2021-08-17.

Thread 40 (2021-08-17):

Implement Arduino Test of LiPo Fuel Gauge

AJGEmbedded, 2021-08-17:
Implement a test of the Qwiic LiPo Fuel gauge using Arduino for testing

AJGEmbedded, 2021-08-17:
Leaving the system on for a while as the battery drains to complete testing

AJGEmbedded, 2021-08-17:
I observed that the statement of charge read has decreased from 61.81% to 61.66%  While this is going on, I will prepare the cable that connects from the fuel gauge back to the SparkFun Thing Plus so that it may be powered by the battery while connected to the FuelGauge

AJGEmbedded, 2021-08-18:
The test has been successful, however the appropriate crimp and housing will need to be ordered for the cable.  That will need to be taken care of in a different issue.  The statement of charge has changed as expected and this can be accurately marked as closed

Closed 2021-08-18.

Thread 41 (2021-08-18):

Arduino Implementation of a test for the Display Module portion of the LCD15143

AJGEmbedded, 2021-08-18:
Test the LCD15143's display module to verify functionality using arduino.  The purpose of this is to see what can I do with the display module by itself.  Test it's ability to draw both images and text.

AJGEmbedded, 2021-08-18:
I have successfully tested its ability to draw colored rectangles, but now I would like to draw text on the display as well.  Since a hand-held video game is bound to have both images and text it is important to have the display write text.

AJGEmbedded, 2021-08-18:
By this same token, I would also like to reduce the serial output as much as possible, so that I only output to serial for debugging purposes.

AJGEmbedded, 2021-08-19:
Text will need to be implemented by drawing each printable character.  This should be implemented using a finite state machine.

AJGEmbedded, 2021-08-19:
Turns out that print and println are defined and do not need to be implemented, however, the current layout is in portrait.  For this application, it will need to be done in landscape.  If this cannot be configured with the given driver, a modification to the existing driver may be required.

AJGEmbedded, 2021-08-19:
It would also be nice to incorporate the LEDC module for pwm as well.  Driver modification to accommodate both PWM and going between portrait and landscape should be in a separate issue.

AJGEmbedded, 2021-08-19:
Basic drawing and displaying text is working correctly here.

Closed 2021-08-19.

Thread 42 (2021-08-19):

Arduino Implementation - add PWM Capability to Display Module

AJGEmbedded, 2021-08-19:
The SparkFun HyperDisplay module does not have support for the PWM capabilities of the ESP32.  Would like to add this capability.

AJGEmbedded, 2021-08-19:
Using the LEDC functionality from the ESP32 hardware libraries, it might be simplest to ignore the backlight setting on the display module and after initializing the display to configure the backlight using LEDC

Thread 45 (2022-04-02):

Qwiic FuelGauge exhaustive testing

AJGEmbedded, 2022-04-02:
Since the fuel gauge worked successfully, some more exhaustive testing is necessary to verify that the fuel gauge can successfully track power drain and perhaps even estimate time remaining on battery life.

AJGEmbedded, 2022-04-02:
so far the fuel gauge is working correctly, can see a small drop after the SOC reading  currently at 55.363% with voltage at 3.904V

AJGEmbedded, 2022-04-02:
to estimate the time remaining on battery life, the interval for reading the data needs to reduced significantly otherwise there will be no change in the statement of charge between readings which will result in an error when attempting to perform the calculation.  Using the time interval divided by the difference of statement of charge to provide a time estimate for time remaining on the battery which is crude, but should give a rough estimate.

AJGEmbedded, 2022-04-02:
I have it set to check every ten minutes at the moment and it has a non-zero difference.  Currently it is performing the calculation as follows:  (minutes_between_measurements)*s1/(s1-s0) to give the value in minutes

s1 = statement of charge for current read
s0 = statement of charge for previous read

AJGEmbedded, 2022-04-02:
Will let it run for an hour to give it adequate testing to verify how consistent the numbers are

AJGEmbedded, 2022-04-02:
There is another command I can use to retrieve the approximate charge and discharge rate of the battery per hour CRATE

AJGEmbedded, 2022-04-02:
The fuel gauge calculations have been made more consistent to include both bytes and multiplying by a resolution.  The statement of charge calculation was adding the first byte to a division of the second byte, while this leads to the same result it can look confusing when debugging.

AJGEmbedded, 2022-04-02:
Probably want to prepare a structure to store the information about the battery voltage, charge, time remaining, and whether it is charging or discharging and look into a more efficient method of determining the time remaining calculation to mitigate branching

AJGEmbedded, 2022-04-04:
It would be easier to table this for now after the screen is working so I can display the results on the screen as the battery is being used

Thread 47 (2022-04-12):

Remove branching from functions for the joystick on repetitive calls and add return for qwiic_joystick_read

AJGEmbedded, 2022-04-12:
Remove it statements from functions where calls are expected to be repeated in order to mitigate delays due to branch prediction.

This is first being addressed on the joystick and qwiic controller.  Since qwiic_joystick_read reads three values from the joystick board, it should also read and prioritize the errors as follows:
QWIIC_NOT_INIT -- highest priority
QWIIC_BUSY
QWIIC_NOACK
QWIIC_OK            -- lowest priority

There is a simple method to mitigate branch prediction for these calls by using arrays and/or bitwise operations while maintaining the results.

AJGEmbedded, 2022-04-12:
took it a step further so that any time multiple responses are received it will prioritize them appropriately for all possible errors identified in the qwiic system.  Since the qwiic system does not need all errors, I might switch it back to one for transactions only.

AJGEmbedded, 2022-04-12:
decided it would be best to proceed with setting this up for transactions only.  Since QWIIC_NC only applies to checking if there is a connection to the joystick and QWIIC_BAD_ADDR only applies for address changes they will not be included.

Similarly QWIIC_INVALID_SPEED and QWIIC_FAIL only apply to initializing the bus (called when adding the joystick).  These are not returned regularly.

When trying to check for a connection to the joystick it has to send a message through the bus to see if a response occurs.  This is not very efficient to do on every call.

AJGEmbedded, 2022-04-12:
There should not need to be any additional changes to the qwiic joystick driver at this point.  The changes referred to here have been addressed in 2022-04-11-JoystickV2.1

Closed 2022-04-12.

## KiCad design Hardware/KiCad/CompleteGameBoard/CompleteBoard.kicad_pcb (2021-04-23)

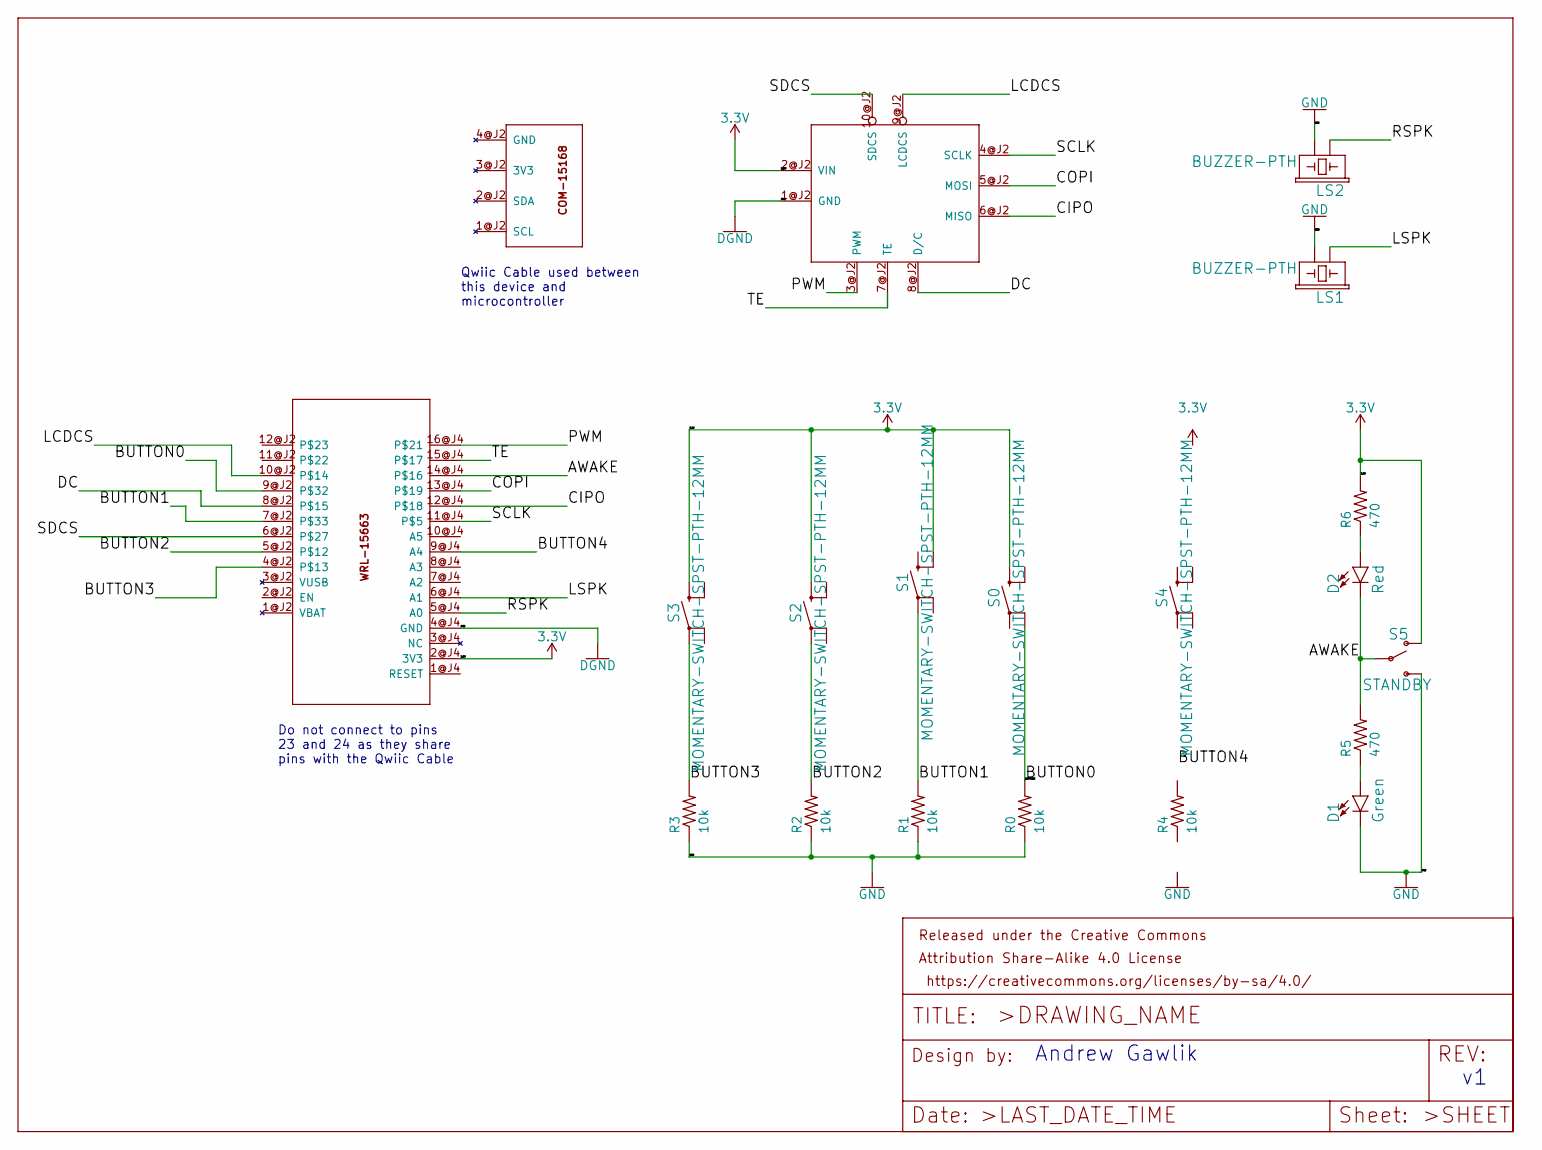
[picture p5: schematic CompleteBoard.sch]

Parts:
A1: ESP32_MICROCONTROLLER; WRL-17381
A2: TFT; LCD-15143
A3: COM-15168
D1: Green; LED_5MM-KIT
D2: Red; LED_5MM-KIT
FRAME1: 001; CREATIVE_COMMONS
LS1, LS2: BUZZER-PTH; BUZZER-12MM
R0, R1, R2, R3, R4: 10k; 0204_5
R5, R6: 470; 0204_5
S0, S1, S2, S3, S4: MOMENTARY-SWITCH-SPST-PTH-12MM; TACTILE_SWITCH_PTH_12MM
S5: STANDBY; SWITCH_SPDT_PTH_11.6X4.0MM

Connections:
3.3V: A1.2@J4 (3V3), A2.2@J2 (VIN), R6.2, S0.3, S1.4, S2.3, S3.3, S4.4, S5.1 (O)
AWAKE: A1.14@J4, D2.K (C), R5.2, S5.2
BUTTON0: A1.9@J2, R0.2, S0.2
BUTTON1: A1.7@J2, R1.2, S1.1
BUTTON2: A1.5@J2, R2.2, S2.1
BUTTON3: A1.4@J2, R3.2, S3.1
BUTTON4: A1.9@J4 (A4), R4.2, S4.1
CIPO: A1.12@J4, A2.6@J2 (MISO)
COPI: A1.13@J4, A2.5@J2 (MOSI)
DC: A1.8@J2, A2.8@J2 (D/C)
GND: A1.4@J4 (GND), A2.1@J2 (GND), D1.K (C), LS1.- (2), LS2.- (2), R0.1, R1.1, R2.1, R3.1, R4.1, S5.3 (S)
LCDCS: A1.10@J2, A2.9@J2 (LCDCS)
LSPK: A1.6@J4 (A1), LS1.+ (1)
unnamed: D1.A, R5.1
unnamed: D2.A, R6.1
PWM: A1.16@J4, A2.3@J2 (PWM)
RSPK: A1.5@J4 (A0), LS2.+ (1)
SCLK: A1.11@J4, A2.4@J2 (SCLK)
SDCS: A1.6@J2, A2.10@J2 (SDCS)
TE: A1.15@J4, A2.7@J2 (TE)

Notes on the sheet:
Andrew Gawlik
Qwiic Cable used between this device and microcontroller
Do not connect to pins 23 and 24 as they share pins with the Qwiic Cable

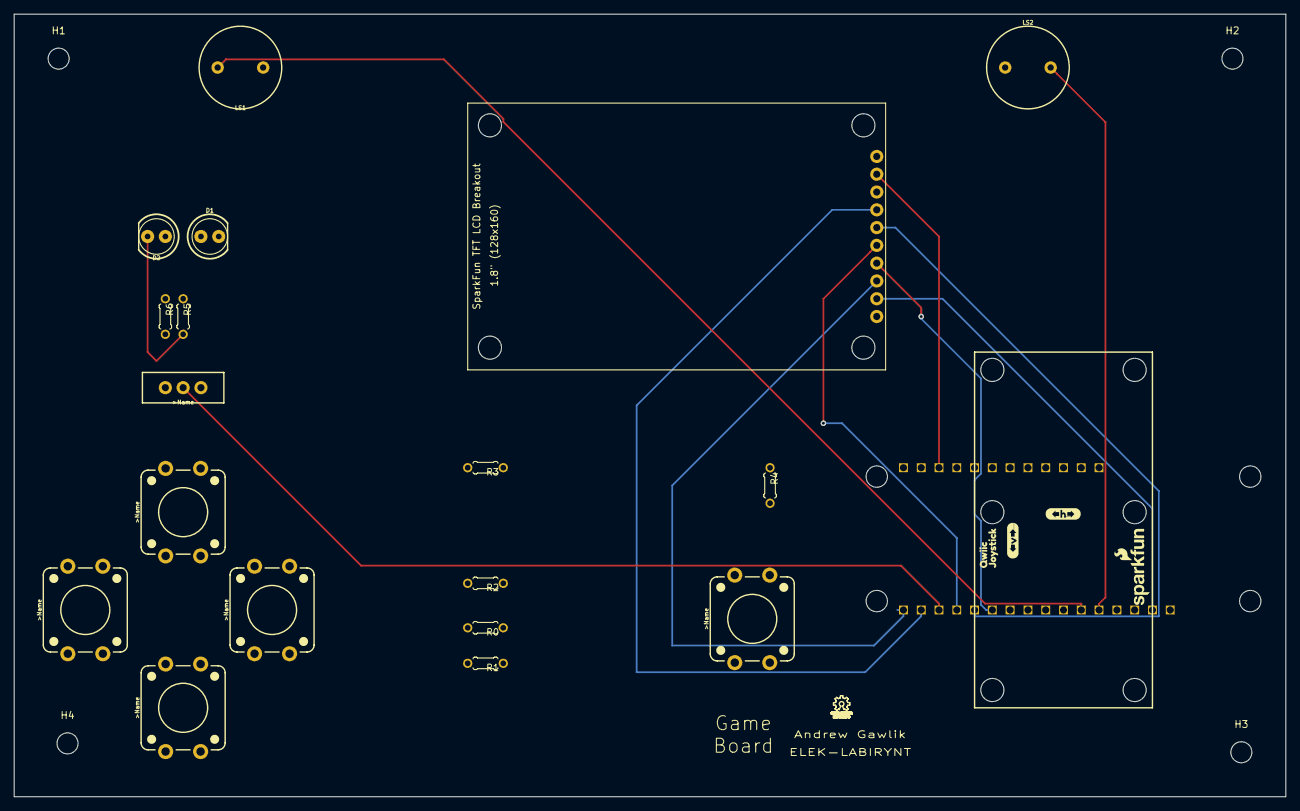
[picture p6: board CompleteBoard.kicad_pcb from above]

Board: 4 copper layers, 181.6 x 111.8 mm, 26 parts (0 on the bottom side), 20 nets.

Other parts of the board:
FRAME1#2: 001; CREATIVE_COMMONS
H1, H2, H3, H4: MountingHole; MountingHole_3mm

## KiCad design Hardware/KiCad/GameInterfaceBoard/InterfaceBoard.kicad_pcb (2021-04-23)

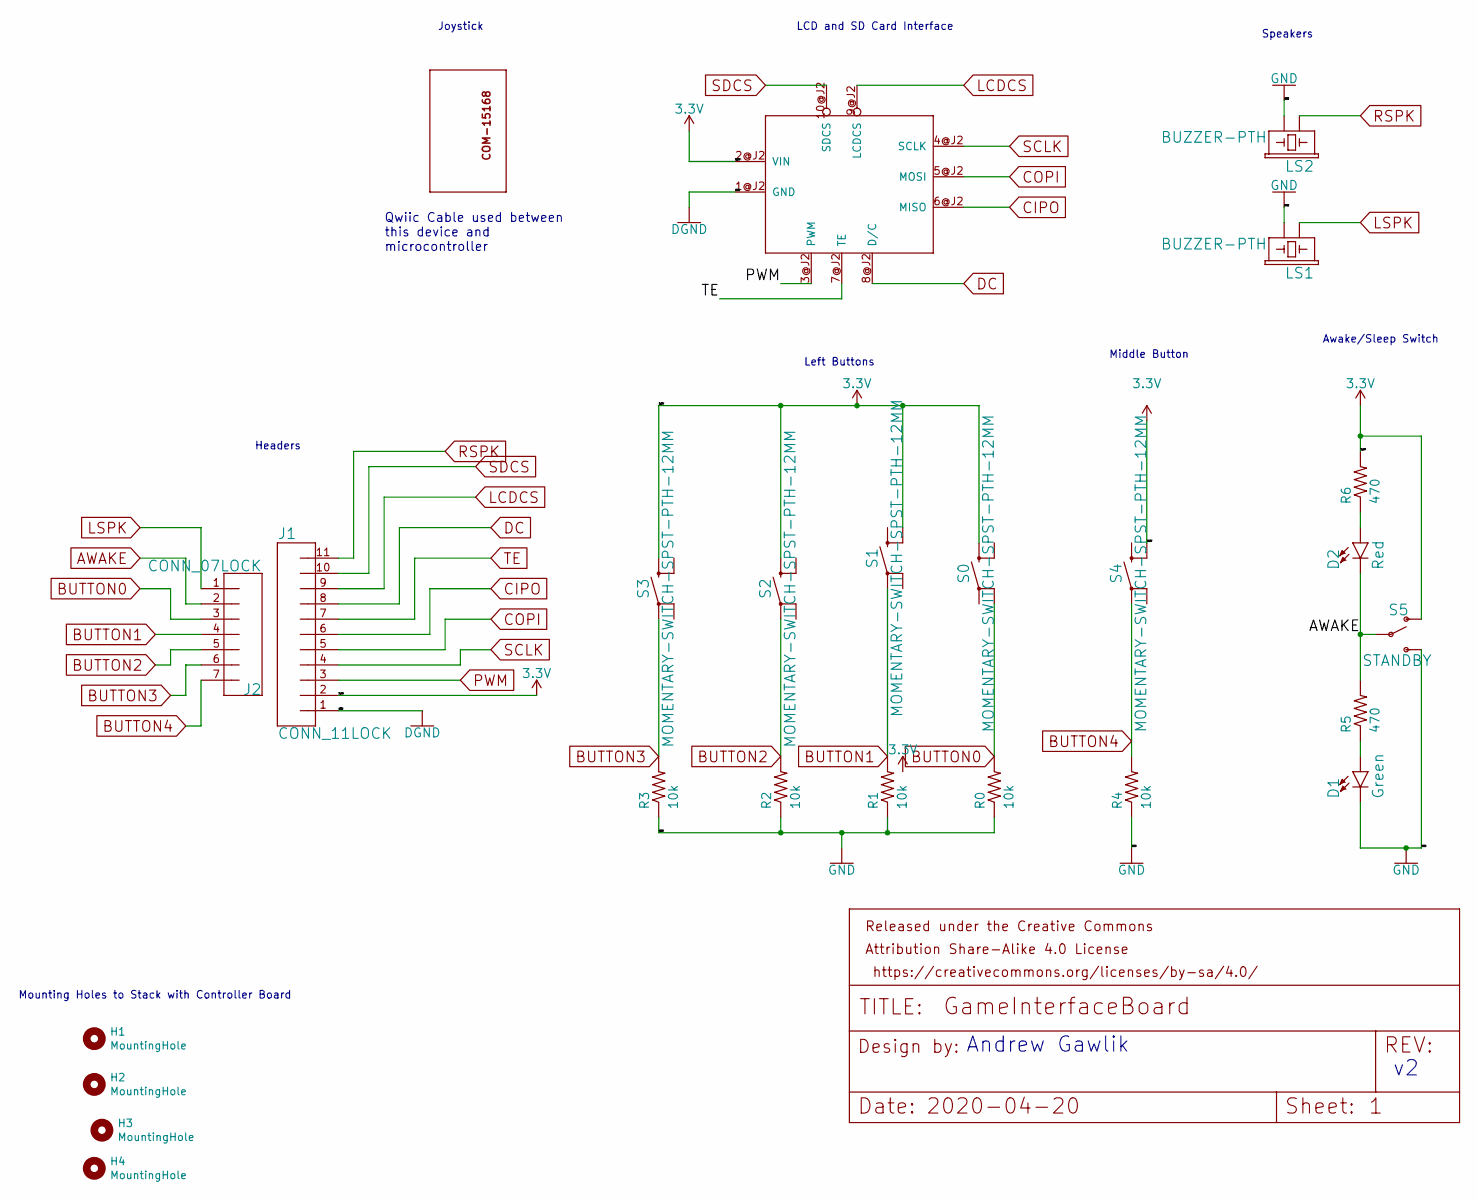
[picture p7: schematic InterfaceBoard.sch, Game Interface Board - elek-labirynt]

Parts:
A2: TFT; LCD-15143
A3: COM-15168
D1: Green; LED_5MM-KIT
D2: Red; LED_5MM-KIT
FRAME1: FRAME-LETTER; CREATIVE_COMMONS
H1, H2, H3, H4: MountingHole; MountingHole_3mm
J1: CONN_11LOCK; 1X11_LOCK
J2: CONN_07LOCK; 1X07_LOCK
LS1, LS2: BUZZER-PTH; BUZZER-12MM
R0, R1, R2, R3, R4: 10k; 0204_5
R5, R6: 470; 0204_5
S0, S1, S2, S3, S4: MOMENTARY-SWITCH-SPST-PTH-12MM; TACTILE_SWITCH_PTH_12MM
S5: STANDBY; SWITCH_SPDT_PTH_11.6X4.0MM

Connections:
3.3V: A2.2@J2 (VIN), J1.2, R6.2, S0.3, S1.4, S2.3, S3.3, S4.4, S5.1 (O)
/AWAKE: D2.K (C), J2.2, R5.2, S5.2
/BUTTON0: J2.3, R0.2, S0.2
/BUTTON1: J2.4, R1.2, S1.1
/BUTTON2: J2.5, R2.2, S2.1
/BUTTON3: J2.6, R3.2, S3.1
/BUTTON4: J2.7, R4.2, S4.1
/CIPO: A2.6@J2 (MISO), J1.6
/COPI: A2.5@J2 (MOSI), J1.5
/DC: A2.8@J2 (D/C), J1.8
/LCDCS: A2.9@J2 (LCDCS), J1.9
/LSPK: J2.1, LS1.+ (1)
/PWM: A2.3@J2 (PWM), J1.3
/RSPK: J1.11, LS2.+ (1)
/SCLK: A2.4@J2 (SCLK), J1.4
/SDCS: A2.10@J2 (SDCS), J1.10
/TE: A2.7@J2 (TE), J1.7
GND: A2.1@J2 (GND), D1.K (C), J1.1, LS1.- (2), LS2.- (2), R0.1, R1.1, R2.1, R3.1, R4.1, S5.3 (S)
unnamed: D1.A, R5.1
unnamed: D2.A, R6.1

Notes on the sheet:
Andrew Gawlik
Qwiic Cable used between this device and microcontroller
Headers
Left Buttons
Middle Button
Awake/Sleep Switch
Speakers
LCD and SD Card Interface
Joystick
Mounting Holes to Stack with Controller Board

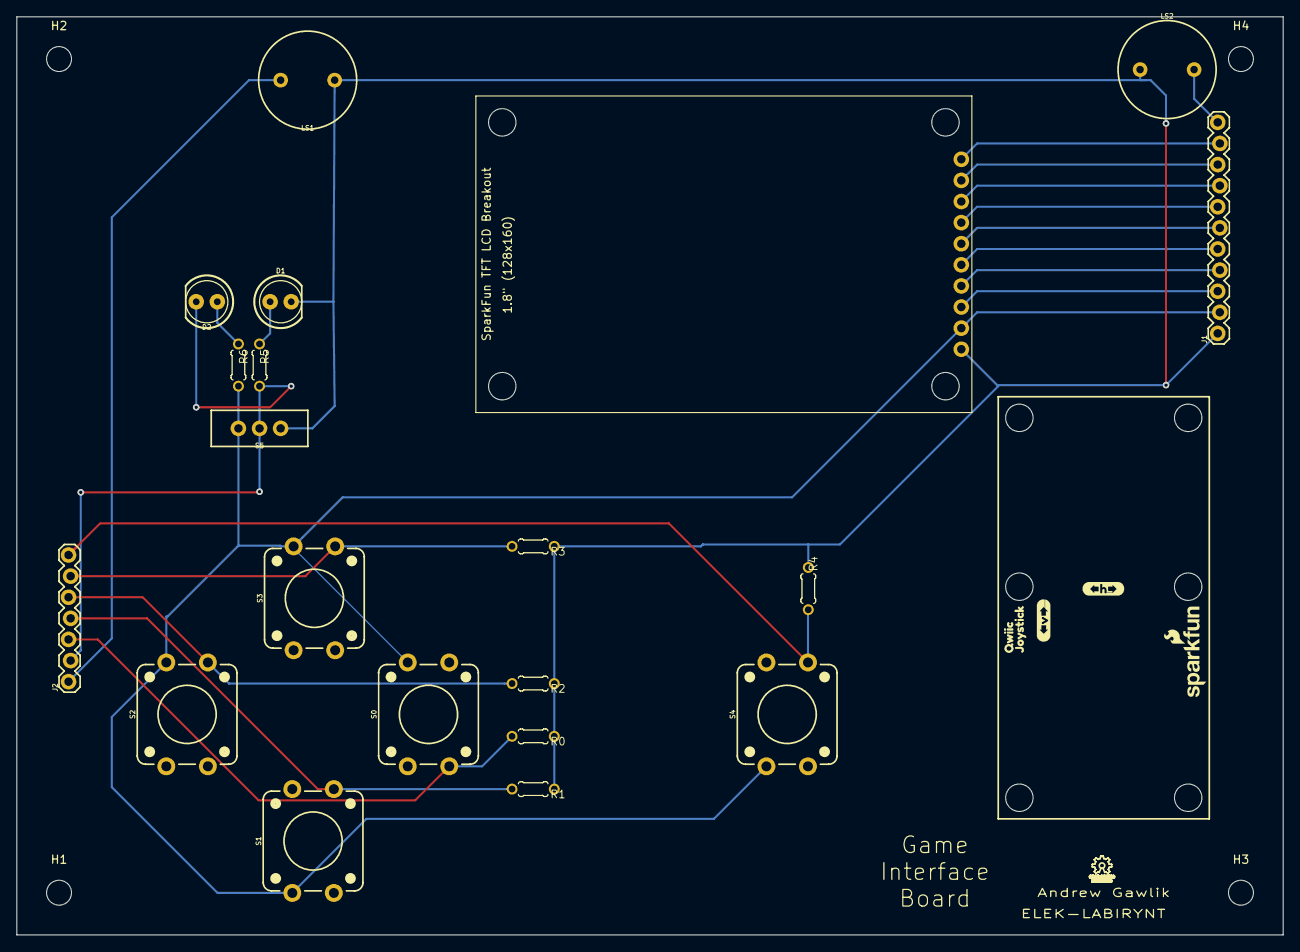
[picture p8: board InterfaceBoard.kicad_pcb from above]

Board: 2 copper layers, 152.4 x 110.5 mm, 29 parts (0 on the bottom side), 20 nets.

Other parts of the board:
FRAME1#2, FRAME2, FRAME3: FRAME-LETTER; CREATIVE_COMMONS

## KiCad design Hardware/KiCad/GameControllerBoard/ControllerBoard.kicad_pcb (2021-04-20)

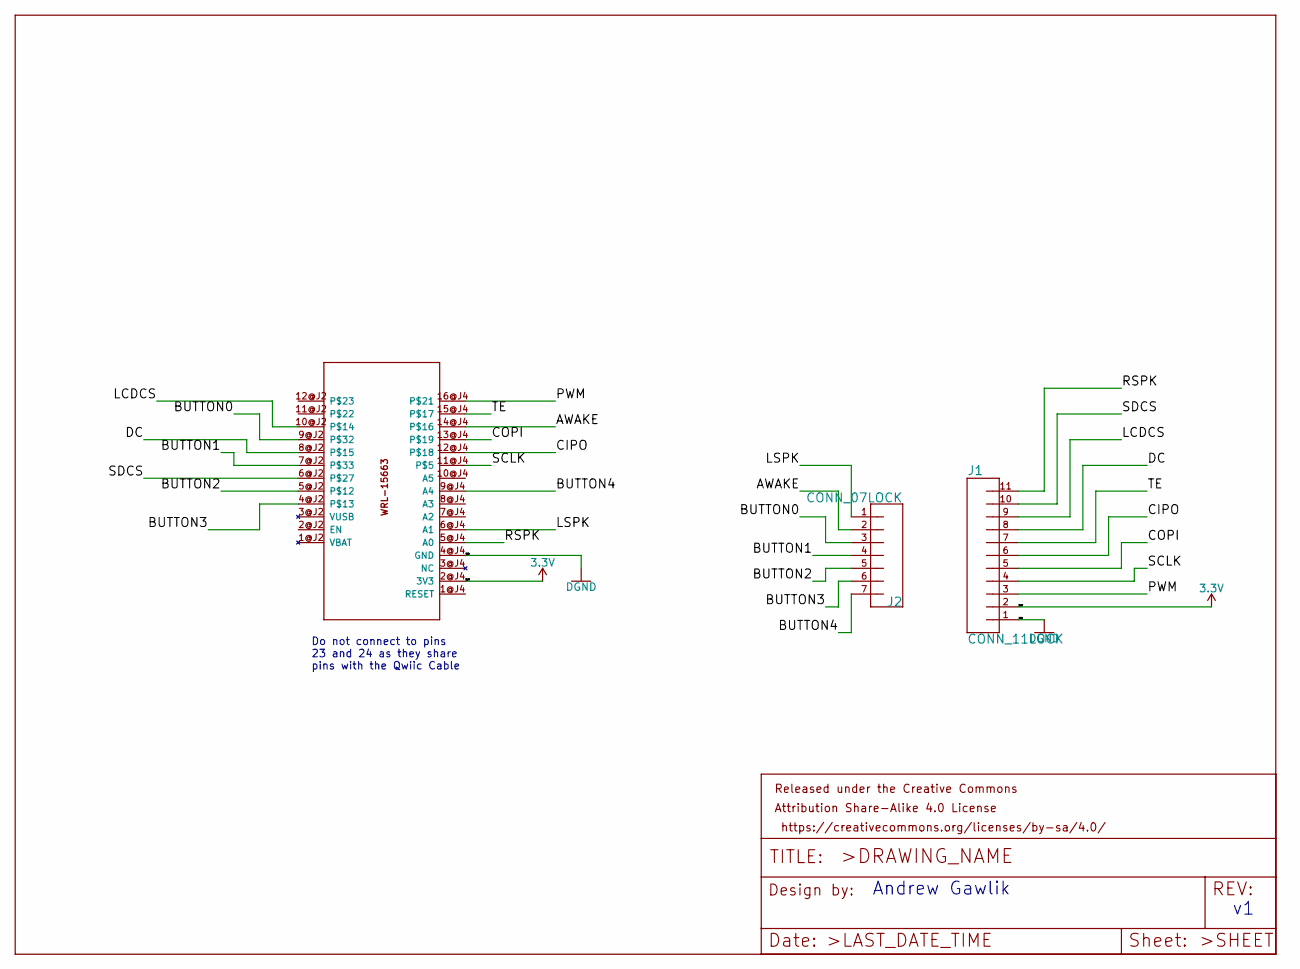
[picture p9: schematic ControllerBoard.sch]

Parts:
A1: ESP32_MICROCONTROLLER; WRL-17381
FRAME1: FRAME-LETTER; CREATIVE_COMMONS
J1: CONN_11LOCK; 1X11_LOCK
J2: CONN_07LOCK; 1X07_LOCK

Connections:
3.3V: A1.2@J4 (3V3), J1.2
/AWAKE: A1.14@J4, J2.2
/BUTTON0: A1.9@J2, J2.3
/BUTTON1: A1.7@J2, J2.4
/BUTTON2: A1.5@J2, J2.5
/BUTTON3: A1.4@J2, J2.6
/BUTTON4: A1.9@J4 (A4), J2.7
/CIPO: A1.12@J4, J1.6
/COPI: A1.13@J4, J1.5
/DC: A1.8@J2, J1.8
/LCDCS: A1.10@J2, J1.9
/LSPK: A1.6@J4 (A1), J2.1
/PWM: A1.16@J4, J1.3
/RSPK: A1.5@J4 (A0), J1.11
/SCLK: A1.11@J4, J1.4
/SDCS: A1.6@J2, J1.10
/TE: A1.15@J4, J1.7
GND: A1.4@J4 (GND), J1.1

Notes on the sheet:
Do not connect to pins 23 and 24 as they share pins with the Qwiic Cable
Andrew Gawlik

Board: 2 copper layers, 4 parts (0 on the bottom side), 18 nets, no tracks yet.

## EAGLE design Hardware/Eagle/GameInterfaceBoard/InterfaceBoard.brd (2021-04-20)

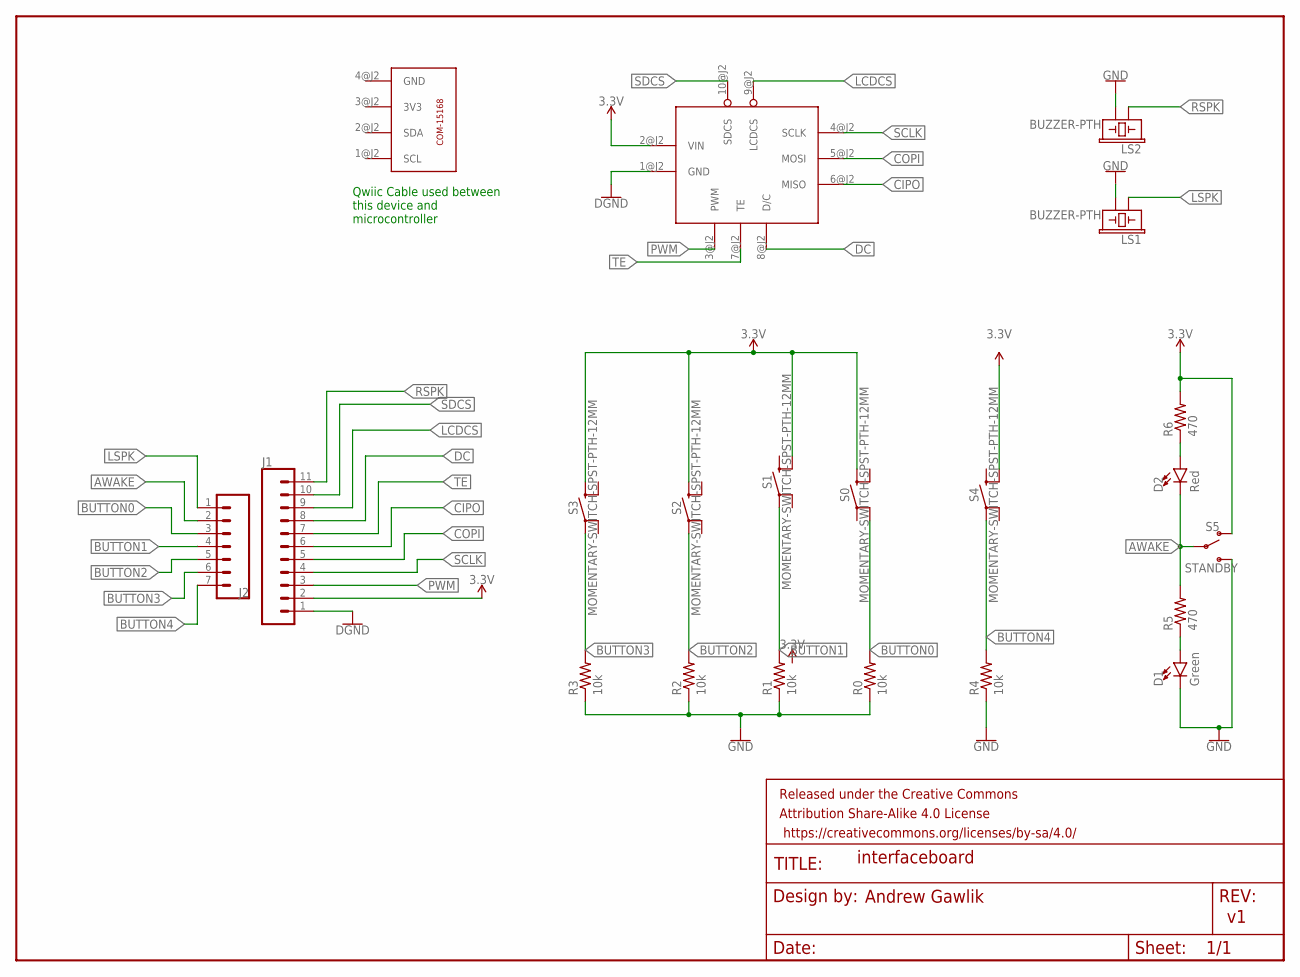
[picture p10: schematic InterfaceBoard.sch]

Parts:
A2: TFT; LCD-15143
A3: COM-15168
D1: Green; LED_5MM-KIT
D2: Red; LED_5MM-KIT
FRAME1: FRAME-LETTER; CREATIVE_COMMONS
J1: CONN_11LOCK; 1X11_LOCK
J2: CONN_07LOCK; 1X07_LOCK
LS1, LS2: BUZZER-PTH; BUZZER-12MM
R0, R1, R2, R3, R4: 10k; 0204/5
R5, R6: 470; 0204/5
S0, S1, S2, S3, S4: MOMENTARY-SWITCH-SPST-PTH-12MM; TACTILE_SWITCH_PTH_12MM
S5: STANDBY; SWITCH_SPDT_PTH_11.6X4.0MM

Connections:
3.3V: A2.2@J2 (VIN), J1.2, R6.2, S0.3, S1.4, S2.3, S3.3, S4.4, S5.1 (O)
AWAKE: D2.K (C), J2.2, R5.2, S5.2
BUTTON0: J2.3, R0.2, S0.2
BUTTON1: J2.4, R1.2, S1.1
BUTTON2: J2.5, R2.2, S2.1
BUTTON3: J2.6, R3.2, S3.1
BUTTON4: J2.7, R4.2, S4.1
CIPO: A2.6@J2 (MISO), J1.6
COPI: A2.5@J2 (MOSI), J1.5
DC: A2.8@J2 (D/C), J1.8
GND: A2.1@J2 (GND), D1.K (C), J1.1, LS1.- (2), LS2.- (2), R0.1, R1.1, R2.1, R3.1, R4.1, S5.3 (S)
LCDCS: A2.9@J2 (LCDCS), J1.9
LSPK: J2.1, LS1.+ (1)
unnamed: D1.A, R5.1
unnamed: D2.A, R6.1
PWM: A2.3@J2 (PWM), J1.3
RSPK: J1.11, LS2.+ (1)
SCLK: A2.4@J2 (SCLK), J1.4
SDCS: A2.10@J2 (SDCS), J1.10
TE: A2.7@J2 (TE), J1.7

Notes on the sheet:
Andrew Gawlik
Qwiic Cable used between this device and microcontroller

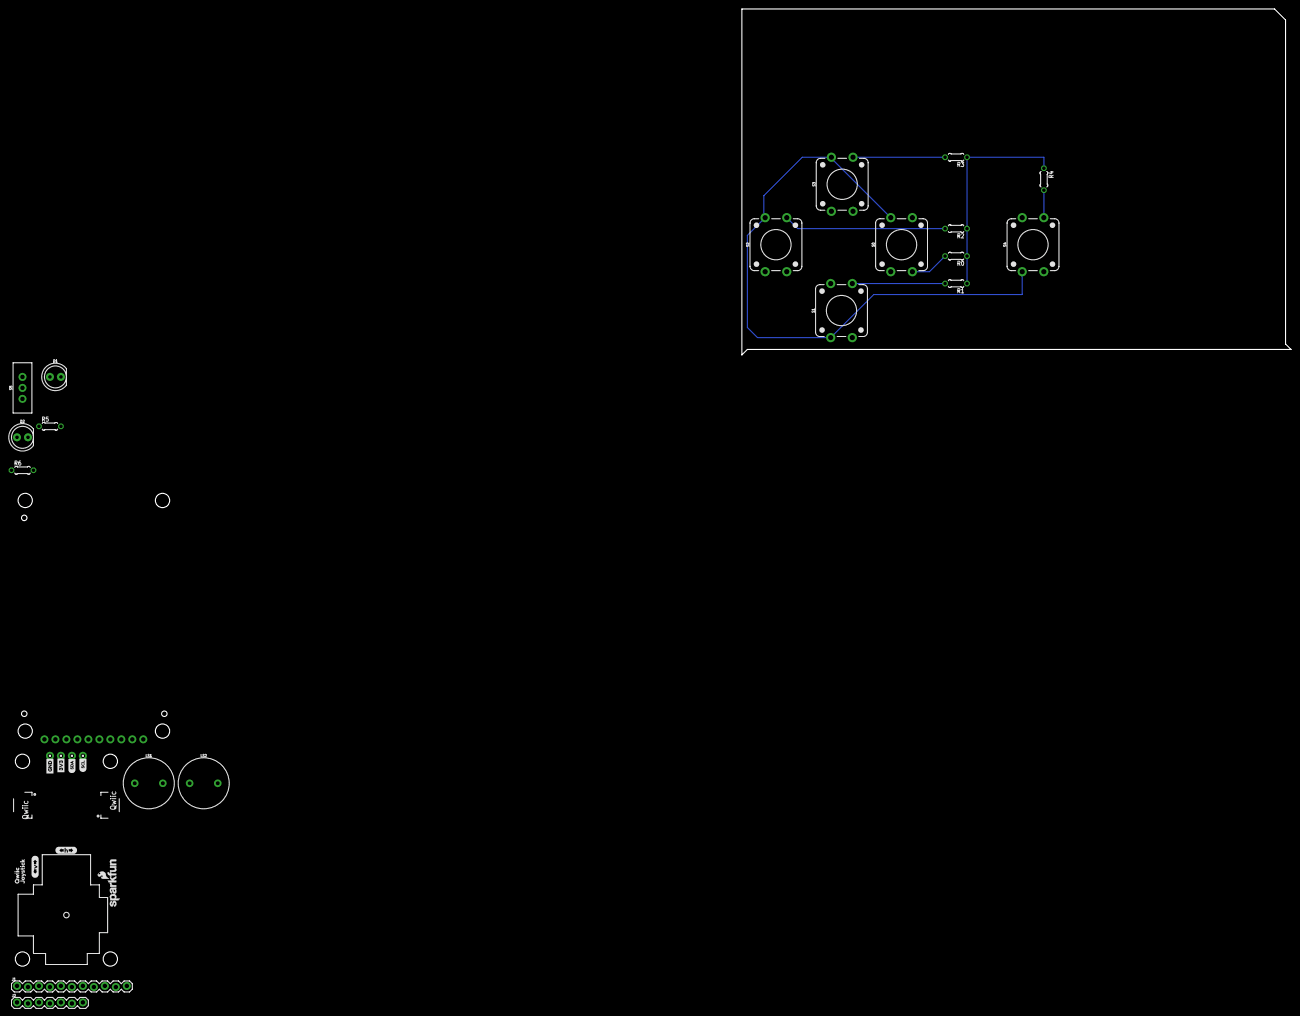
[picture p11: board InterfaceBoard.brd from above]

Board: 2 copper layers, 127.0 x 80.0 mm, 22 parts (0 on the bottom side), 20 nets.

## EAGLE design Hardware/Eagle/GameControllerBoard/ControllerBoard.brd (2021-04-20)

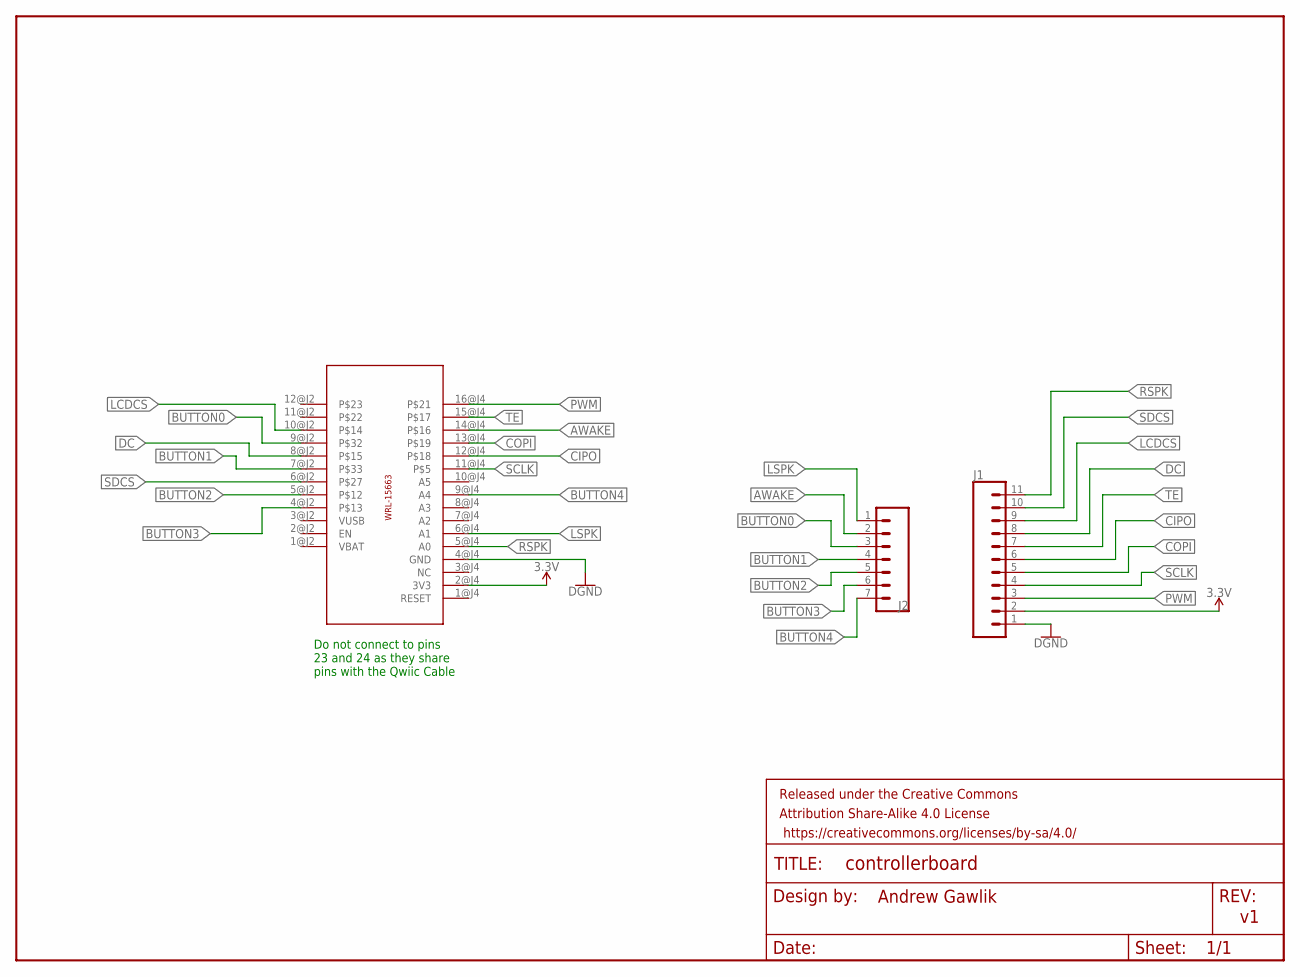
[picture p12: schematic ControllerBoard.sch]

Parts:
A1: ESP32_MICROCONTROLLER; WRL-17381
FRAME1: FRAME-LETTER; CREATIVE_COMMONS
J1: CONN_11LOCK; 1X11_LOCK
J2: CONN_07LOCK; 1X07_LOCK

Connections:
3.3V: A1.2@J4 (3V3), J1.2
AWAKE: A1.14@J4, J2.2
BUTTON0: A1.9@J2, J2.3
BUTTON1: A1.7@J2, J2.4
BUTTON2: A1.5@J2, J2.5
BUTTON3: A1.4@J2, J2.6
BUTTON4: A1.9@J4 (A4), J2.7
CIPO: A1.12@J4, J1.6
COPI: A1.13@J4, J1.5
DC: A1.8@J2, J1.8
GND: A1.4@J4 (GND), J1.1
LCDCS: A1.10@J2, J1.9
LSPK: A1.6@J4 (A1), J2.1
PWM: A1.16@J4, J1.3
RSPK: A1.5@J4 (A0), J1.11
SCLK: A1.11@J4, J1.4
SDCS: A1.6@J2, J1.10
TE: A1.15@J4, J1.7

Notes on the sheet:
Do not connect to pins 23 and 24 as they share pins with the Qwiic Cable
Andrew Gawlik

Board: 2 copper layers, 4 parts (0 on the bottom side), 18 nets, no tracks yet.

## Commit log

2021-02-01 Update README.md
    Added my current goals for project
2021-02-01 Adding current progress of PCB design which includes GPIO buttons
    [InterfaceBoard.brd, InterfaceBoard.sch]
2021-02-01 Adding expected bill of materials intended to be used as of 2021-02-01
    [Bill of Materials.ods]
2021-02-01 added 'designed by' in schematic
    [InterfaceBoard.sch]
2021-02-01 Specified button colors and added Designed by in the PCB layout
    [InterfaceBoard.brd, InterfaceBoard.sch]
2021-02-01 Added speakers to PCB layout
    [InterfaceBoard.brd, InterfaceBoard.sch]
2021-02-09 Update Bill of Materials.ods
    Filled in details of draft for the Bill of Materials. At present the Custom PCB may be changed contingent on costs. A backup plan is to consider implementing on protoboards following the traces for a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
    [Bill of Materials.ods]
2021-02-19 Added SD card to bill of materials for the project
    [Bill of Materials.ods]
2021-02-19 Added LED and power switch to BOM
    [Bill of Materials.ods]
2021-02-19 Added the reference for the 10kOhm resistors and the extended cost; also included currency formatting.
    [Bill of Materials.ods]
2021-04-12 Updated BOM to reflect reduction of buttons in Issue #8
    [Bill of Materials.ods]
2021-04-14 First Iteration of FreeRTOS UART driver for testing microcontroller for issue #9
2021-04-14 Update README.md
    updated to reflect my own description of the driver rather than the example hello_world that was used to construct the driver
2021-04-14 Delete hello_world_main.c
    this was an example file and is not relevant to the driver I am creating...
2021-04-15 Update README.md
    included reference to KiCAD for the PCB design to allow for building the design of a PCB beyond the limitations of the free version of EagleCAD
2021-04-16 Added comments for the driver in issue #10
2021-04-17 Updated Parts on Interface board for Issue #2, need to reroute traces considering the overhaul
    [InterfaceBoard.brd, InterfaceBoard.sch]
2021-04-17 Added Game Controller Board design for issue #7
    [ControllerBoard.brd, ControllerBoard.sch]
2021-04-17 Added complete controller board minus traces for issue #12
    [CompleteBoard.brd, CompleteBoard.sch]
2021-04-17 Imported Complete Game Board from EagleCAD to KiCad for work on issue #12
2021-04-19 Started placement of parts and added some traces for complete board referenced in issue #12
    [CompleteBoard.kicad_pcb, CompleteBoard.sch]
2021-04-20 Updated Wiring and parts for issue #12 so that through hole buttons are used
    [CompleteBoard.brd, CompleteBoard.sch]
2021-04-20 Added reference for button 4 for issue #7
    [ControllerBoard.brd, ControllerBoard.sch]
2021-04-20 Added connection for button 4 and updated buttons to use through hole version and switched pins for easier connection on issue #2
    [InterfaceBoard.brd, InterfaceBoard.sch]
2021-04-20 Imported EagleCAD project into KiCad for issue #2
2021-04-20 Imported EagleCAD design to KiCad for issue #7
    [ControllerBoard.kicad_pcb, ControllerBoard.sch]
2021-04-20 Re-imported updated EagleCAD board for issue #12
    [CompleteBoard.kicad_pcb, CompleteBoard.sch]
2021-04-20 Wired Traces for PCB on issue #2
    [InterfaceBoard.kicad_pcb, InterfaceBoard.sch]
2021-04-20 Added Silk Screen, board outline and updated KiCad frame as indicated on issue #2
    [InterfaceBoard.kicad_pcb]
2021-04-20 Added OpenHardware Logo to schematic for KiCad on issue #2
    [InterfaceBoard.sch]
2021-04-21 Added drill holes for issue #2
    [InterfaceBoard.kicad_pcb, InterfaceBoard.sch]
2021-04-21 Updated Footprints for the Interface Board as requested on issue #15
    [InterfaceBoard.kicad_pcb]
2021-04-21 Removed excess drill holes as requested on issue #17
    [InterfaceBoard.kicad_pcb, InterfaceBoard.sch]
2021-04-21 Controller board and interface board have been added to the drawing for separate boards version of FreeCAD assembly drawing for issue #16
    [Assembly with Complete Board.FCStd, Assembly with Separate Boards.FCStd, ControllerBoard.step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]
2021-04-22 updated library footprints and symbols for Interface Board as indicated on #15
    [InterfaceBoard.sch]
2021-04-22 updated library footprints and symbols for Controller Board as indicated on #15
2021-04-22 used saved library footprints and symbols from separate boards on the complete version of the board and wired all traces as per #12
2021-04-22 Created Step Export of Complete Board and Imported into FreeCad for issue #16
    [Assembly with Complete Board.FCStd, CompleteBoard.step]
2021-04-22 Added Qwiic Joystick and ESP32 Thing Plus with corresponding header pins to FreeCad design for issue #16
    [Assembly with Complete Board.FCStd, Assembly with Separate Boards.FCStd]
2021-04-22 Added LCD/SD card breakout and pin headers along with the pin headers for the interface/controller board for issue #16 to the FreeCad Drawings
    [Assembly with Complete Board.FCStd, Assembly with Separate Boards.FCStd]
2021-04-23 Create Acknowledgements
    Added acknowledgements for hardware and cad drawings
2021-04-23 Added drill holes for the Joystick after reimporting the part for issue #20 the interface board is ready, however the traces need to be moved for the 'complete' board
    [CompleteBoard.kicad_pcb]
2021-04-23 Fixed traces for the 'complete board' for issue #20
    [CompleteBoard.kicad_pcb]
2021-04-23 Updated step export files for the boards pertaining to #20 for #16.
    [CompleteBoard.step, InterfaceBoard.step]
2021-04-29 Added reference to the m3 standoffs
    The M3 standoffs referenced in the acknowledgements include the ones chosen for the drawing and they work out really well
2021-04-29 Added reference to hex nuts used for assembly
    Added reference to the acknowledgements for the M3 hex nuts to be used in the assembly drawings
2021-04-29 Updated Complete Version of Board Assembly to include standoffs and nuts
    [Assembly with Complete Board.FCStd]
2021-04-29 Added part hierarchy for the 'complete board'
    [Assembly with Complete Board.FCStd]
2021-04-30 Added reference to the pinouts to help make it easier to identify which pins are available and which pins are assigned for use in driver development
    [Pinouts Assigned.ods]
2021-05-03 Reviewed the datasheets and schematics to correct the pinouts assigned to make driver development easier
    [Pinouts Assigned.ods]
2021-05-03 Updated pins for UART Driver Issue #10
2021-05-03 Added documentation for the header and source files for the UART Driver referenced in issue #10
2021-05-04 Updated comments for issue #10, added new comments for the UART Driver test application
2021-05-04 added .gitignore for drivers to exclude temporary files due to opening an open document spreadsheet
2021-05-05 Updated and restructured the CMakeLists.txt and the directory layout and modularized the files for reusability for issue #10
    [Pinouts Assigned.ods]
2021-05-06 Implemented Test application using a timer with the UART debugger for issue #10
2021-05-10 Updated UART debugger driver to address issue #24 and also renamed all functions to utilize the C namespacing convention, so instead of 'debug_' it is now 'uart_debugger_' in order to make the naming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
2021-05-11 Added string helper for issue #26 and used for testing in the UART Debugger
2021-05-11 Updated date for UART Driver and test files depicting the last date it was updated with success
2021-05-11 Removed UART Debugger from FreeRTOS version as per issue #32, locally it is moved to the Baremetal version folder which will take time to develop; the current priority lies within getting the FreeRTO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
2021-05-14 Moved Pinouts Assigned.ods to root since it is tied to both the hardware and software
    [Pinouts Assigned.ods]
2021-07-01 The FreeRTOS version of the button implementation is mostly implemented. There is still a problem with GPIO33 which I am trying to work out with the forums on ESP32.com
    [Pinouts Assigned.ods]
2021-07-01 Added comments to buttons component for FreeRTOS
2021-07-07 Changed GPIO pin used for button1 from GPIO33 to GPIO4 and observed success
2021-07-07 Updated dates on files and the pinouts spreadsheet reflecting the changes for button1 in software for issue #36
    [Pinouts Assigned.ods]

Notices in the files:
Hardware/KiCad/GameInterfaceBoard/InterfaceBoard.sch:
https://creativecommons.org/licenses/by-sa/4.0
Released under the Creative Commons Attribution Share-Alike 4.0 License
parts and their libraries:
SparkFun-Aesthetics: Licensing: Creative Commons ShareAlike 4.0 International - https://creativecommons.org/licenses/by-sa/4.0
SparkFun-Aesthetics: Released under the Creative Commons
